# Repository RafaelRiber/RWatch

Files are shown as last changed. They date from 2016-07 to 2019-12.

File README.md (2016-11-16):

# RWatch
 
  <p align="center">
 
 <em>Early render of the watch</em>
 
## Short description
The RWatch is a modern and elegant oled "smartwatch" based around the Atmel ATSAMD21-G18A ARM Cortex M0+ Microcontroller, with a 9 DOF IMU and environmental sensing, and everything contained in a PCB the size of the screen.

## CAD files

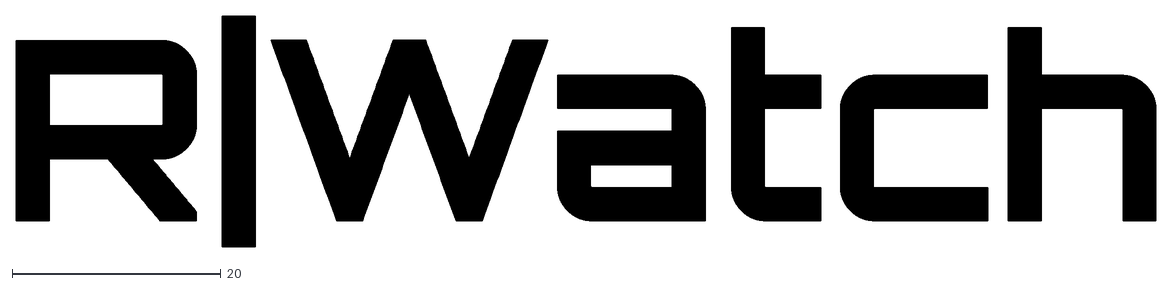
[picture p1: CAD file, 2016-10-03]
Logo/RWatch.dxf
109.3 x 22.1

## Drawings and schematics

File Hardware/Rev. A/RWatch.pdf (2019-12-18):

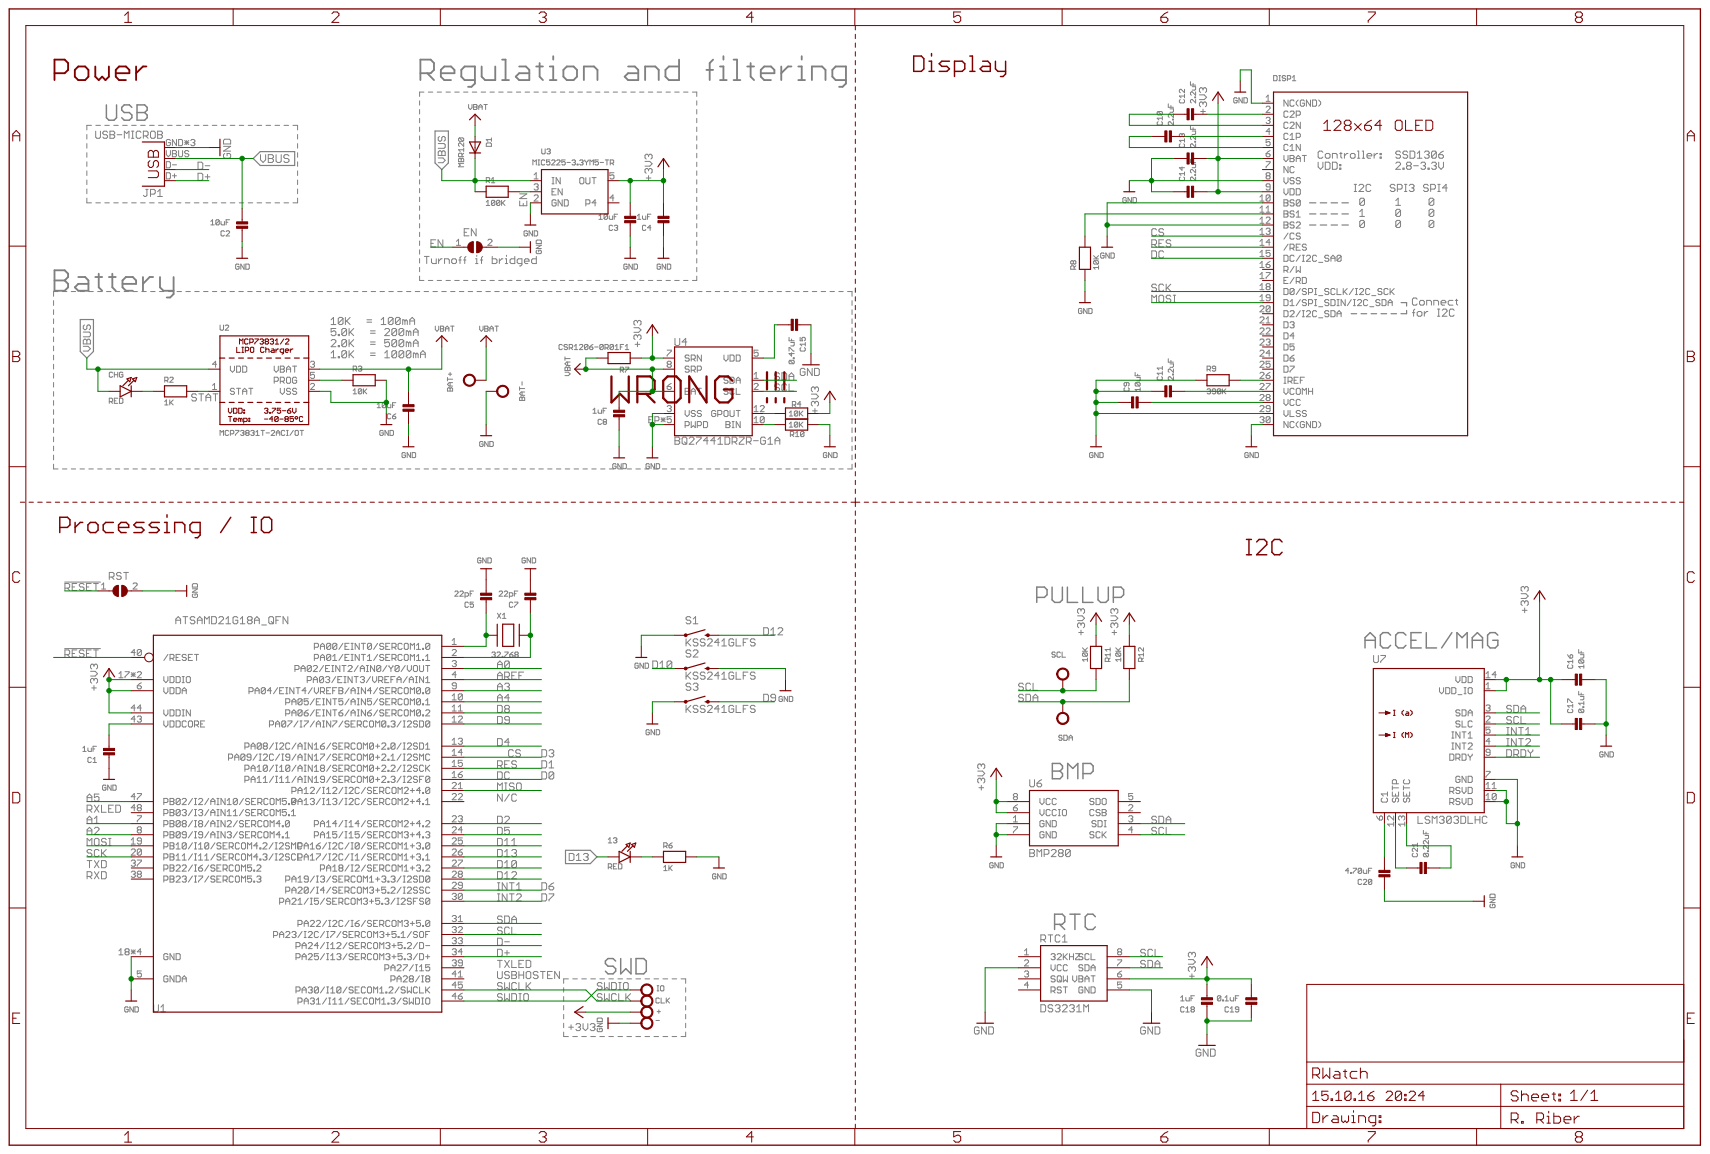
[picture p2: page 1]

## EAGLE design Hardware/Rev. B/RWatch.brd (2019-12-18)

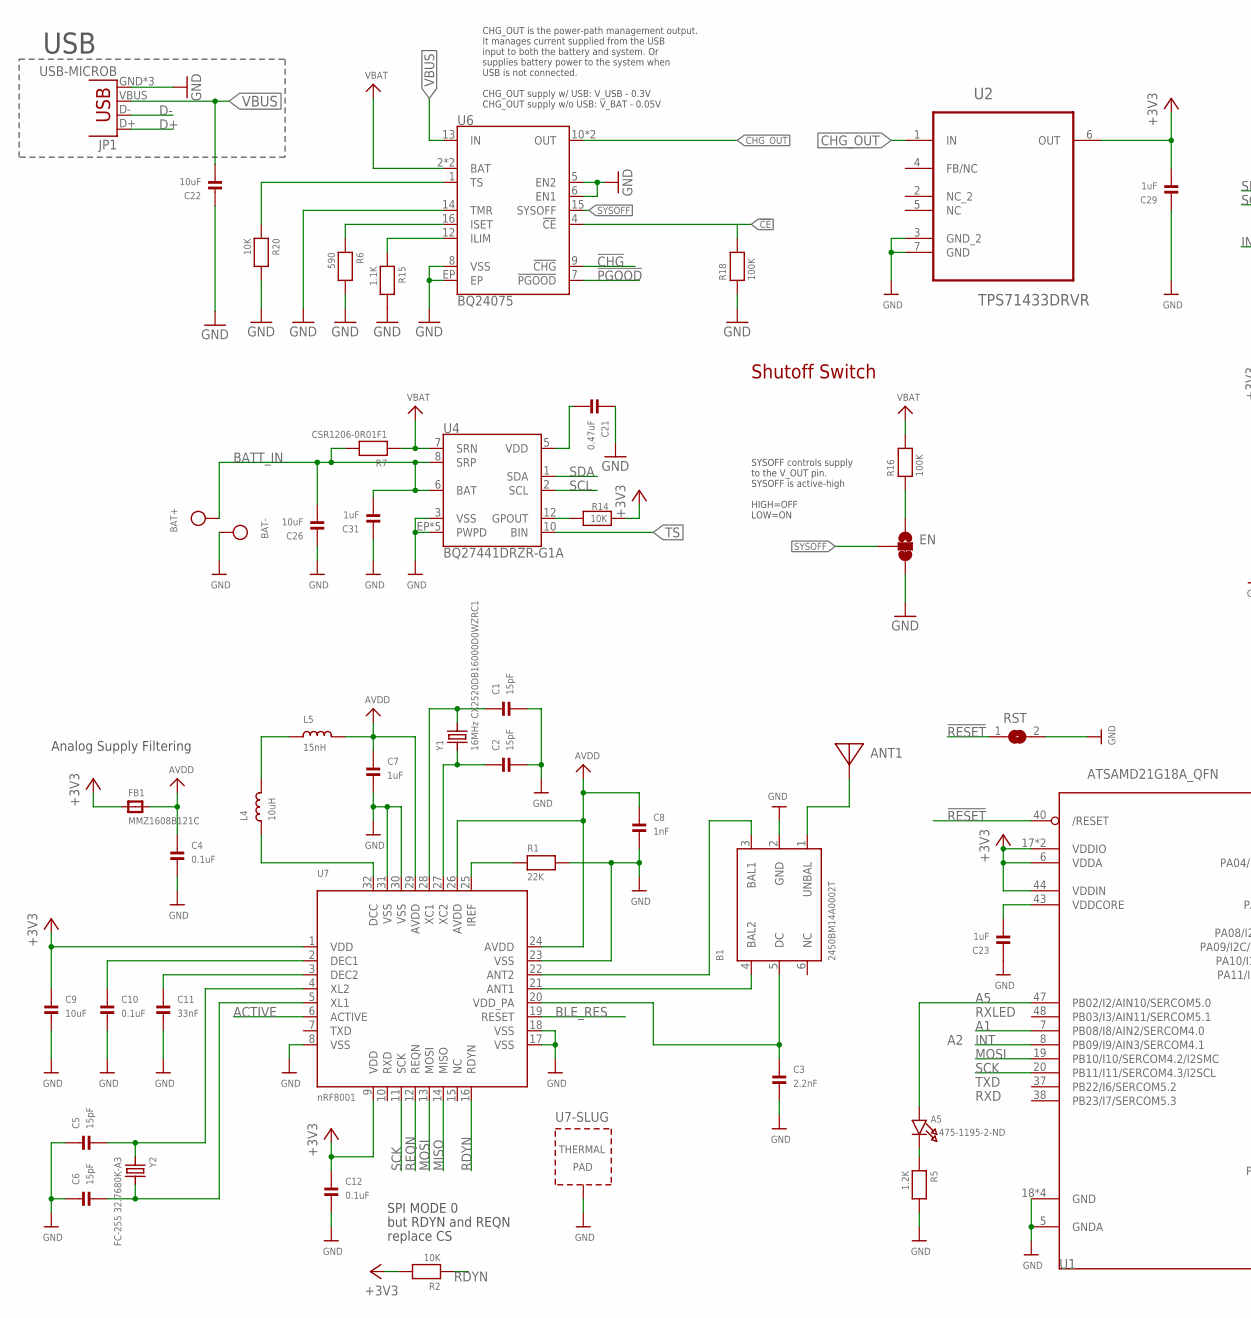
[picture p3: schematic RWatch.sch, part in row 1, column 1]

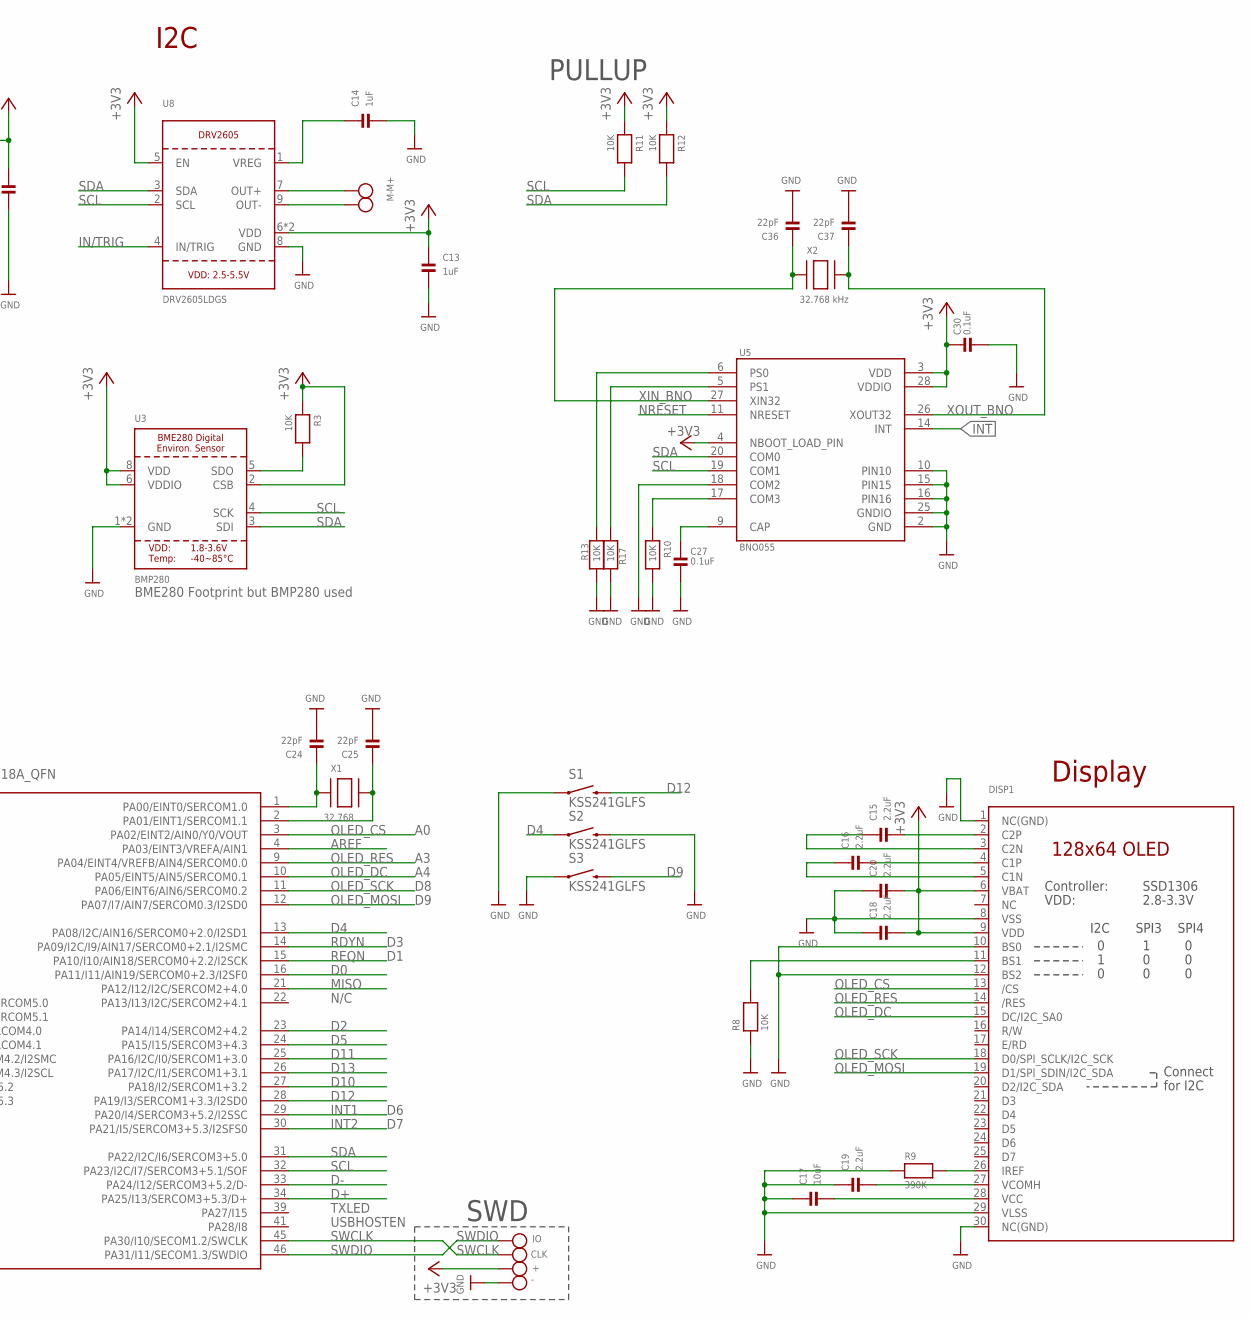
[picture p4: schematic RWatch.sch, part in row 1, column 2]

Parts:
+: TESTPOINTROUND1.5MM; TESTPOINT_ROUND_1.5MM
-: TESTPOINTROUND1.5MM; TESTPOINT_ROUND_1.5MM
A5: 475-1195-2-ND; CHIPLED_0603_NOOUTLINE
ANT1: ANTENNA_PCBNRF8001_1.6MM; ANT_PCB_2.4GHZ_NRF8001_1.6MM_1OZ
B1: 2450BM14A0002T; BALUN0603
BAT+: TESTPOINTROUND2MM; TESTPOINT_ROUND_2MM
BAT-: TESTPOINTROUND2MM; TESTPOINT_ROUND_2MM
C1, C2, C5, C6: 15pF; 0402
C3: 2.2nF; 0402
C4, C10, C12, C27, C30: 0.1uF; 0402
C7, C13, C14, C23, C29, C31: 1uF; 0402
C8: 1nF; 0402
C9: 10uF; 0402
C11: 33nF; 0402
C15, C16, C18, C19, C20: 2.2uF; 0402
C17, C22, C26: 10uF; 0603
C21: 0.47uF; 0402
C24, C25, C36, C37: 22pF; 0402
CLK: TESTPOINTROUND1.5MM; TESTPOINT_ROUND_1.5MM
DISP1: DISP_OLED_UG-2864HSWEG01; UG-2864HSWEG01_1.3_WRAPAROUND
EN: JUMPER-PAD-3-2OF3_NC_BY_TRACE_SMALL; PAD-JUMPER-3-2OF3_NC_BY_TRACE_YES_SILK_FULL_BOX
FB1: MMZ1608B121C; 0805
IO: TESTPOINTROUND1.5MM; TESTPOINT_ROUND_1.5MM
JP1: USB-MICROB; MPN 10104110-0001LF
L4: 10uH; _0603
L5: 15nH; _0603
M+: TESTPOINTROUND2MM; TESTPOINT_ROUND_2MM
M-: TESTPOINTROUND2MM; TESTPOINT_ROUND_2MM
R1: 22K; 0402
R2, R8: 10K; 0402
R3, R10, R11, R12, R13, R14, R17, R20: 10K; 0402; MPN CRCW060310K0FKEA
R5: 1.2K; 0402; MPN MC0063W06031221R
R6: 590; 0402; MPN CRCW060310K0FKEA
R7: CSR1206-0R01F1; 1206
R9: 390K; 0402
R15: 1.1K; 0402; MPN CRCW060310K0FKEA
R16, R18: 100K; 0402; MPN MC0063W06031221R
RST: SOLDERJUMPERREFLOW; SOLDERJUMPER_REFLOW
S1, S2, S3: KSS241GLFS
U1: ATSAMD21G18A_QFN; TQFN48_7MM
U2: TPS71433DRVR; SON65P200X200X80-7N
U3: BMP280; BME280
U4: BQ27441DRZR-G1A; PDSO-N12
U5: BNO055; LGA28R50P4X10_380X520X100
U6: BQ24075; PVQFN-N16
U7: nRF8001; QFN32_5MM
U8: DRV2605LDGS; PSOP10
X1: 32.768; XTAL3215
X2: 32.768 kHz; XTAL3215
Y1: 16MHz CX2520DB16000D0WZRC1; CRYSTAL_2.5X2
Y2: FC-255 32.7680K-A3; CRYSTAL_4.9X1.8

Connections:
!CE!: R18.2, U6.4 (!CE!)
!CHG!: U6.9 (!CHG!)
!PGOOD!: U6.7 (!PGOOD!)
!RESET: RST.1, U1.40 (/RESET)
+3V3: +.P$1, C9.1, C12.1, C13.1, C18.2, C20.2, C29.2, C30.2, DISP1.6 (VBAT), DISP1.9 (VDD), FB1.1, R2.2, R3.1, R11.1, R12.1, R14.1, U1.6 (VDDA), U1.17 (VDDIO), U1.36 (VDDIO), U1.44 (VDDIN), U2.6 (OUT), U3.2 (CSB), U3.6 (VDDIO), U3.8 (VDD), U5.3 (VDD), U5.4 (NBOOT_LOAD_PIN), U5.28 (VDDIO), U7.1 (VDD), U7.9 (VDD), U8.5 (EN), U8.6 (VDD), U8.10 (VDD)
A1: U1.7 (PB08/I8/AIN2/SERCOM4.0)
A5: A5.A, U1.47 (PB02/I2/AIN10/SERCOM5.0)
ACTIVE: U7.6 (ACTIVE)
AREF: U1.4 (PA03/EINT3/VREFA/AIN1)
AVDD: C4.1, C7.1, C8.1, FB1.2, L5.2, U7.24 (AVDD), U7.26 (AVDD), U7.29 (AVDD)
BATT_IN: BAT+.P$1, C26.2, C31.2, R7.2, U4.6 (BAT), U4.8 (SRP)
BLE_RES: U7.19 (RESET)
CHG_OUT: U2.1 (IN), U6.10 (OUT), U6.11 (OUT)
D0: U1.16 (PA11/I11/AIN19/SERCOM0+2.3/I2SF0)
D2: U1.23 (PA14/I14/SERCOM2+4.2)
D4: S2.1, U1.13 (PA08/I2C/AIN16/SERCOM0+2.0/I2SD1)
D5: U1.24 (PA15/I15/SERCOM3+4.3)
D9: S3.2
D10: U1.27 (PA18/I2/SERCOM1+3.2)
D11: U1.25 (PA16/I2C/I0/SERCOM1+3.0)
D12: S1.2, U1.28 (PA19/I3/SERCOM1+3.3/I2SD0)
D13: U1.26 (PA17/I2C/I1/SERCOM1+3.1)
D+: JP1.D+, U1.34 (PA25/I13/SERCOM3+5.3/D+)
D-: JP1.D-, U1.33 (PA24/I12/SERCOM3+5.2/D-)
GND: -.P$1, B1.2 (GND), BAT-.P$1, C1.2, C2.2, C3.2, C4.2, C5.1, C6.1, C7.2, C8.2, C9.2, C10.2, C11.2, C12.2, C13.2, C14.2, C17.1, C18.1, C19.1, C20.1, C21.1, C22.1, C23.1, C24.2, C25.2, C26.1, C27.1, C29.1, C30.1, C31.1, C36.2, C37.2, DISP1.1 (NC(GND)), DISP1.8 (VSS), DISP1.10 (BS0), DISP1.12 (BS2), DISP1.29 (VLSS), DISP1.30 (NC(GND)), EN.3, JP1.GND, JP1.MT1 (GND), JP1.MT2 (GND), R1.2, R5.2, R6.2, R8.1, R9.1, R10.2, R13.2, R15.2, R17.2, R18.1, R20.2, RST.2, S1.1, S2.2, S3.1, U1.5 (GNDA), U1.18 (GND), U1.35 (GND), U1.42 (GND), U1.THERMAL (GND), U2.3 (GND_2), U2.7 (GND), U3.1 (GND), U3.7 (GND), U4.3 (VSS), U4.EP (PWPD), U4.EP1 (PWPD), U4.EP2 (PWPD), U4.EP3 (PWPD), U4.EP4 (PWPD), U5.2 (GND), U5.10 (PIN10), U5.15 (PIN15), U5.16 (PIN16), U5.18 (COM2), U5.25 (GNDIO), U6.5 (EN2), U6.6 (EN1), U6.8 (VSS), U6.14 (TMR), U6.EP, U7.8 (VSS), U7.17 (VSS), U7.18 (VSS), U7.23 (VSS), U7.30 (VSS), U7.31 (VSS), U7.33 (TP), U8.8 (GND)
ILIM: R15.1, U6.12 (ILIM)
IN/TRIG: U8.4 (IN/TRIG)
INT: U1.8 (PB09/I9/AIN3/SERCOM4.1), U5.14 (INT)
INT1: U1.29 (PA20/I4/SERCOM3+5.2/I2SSC)
INT2: U1.30 (PA21/I5/SERCOM3+5.3/I2SFS0)
ISET: R6.1, U6.16 (ISET)
MISO: U1.21 (PA12/I12/I2C/SERCOM2+4.0), U7.14 (MISO)
MOSI: U1.19 (PB10/I10/SERCOM4.2/I2SMC), U7.13 (MOSI)
unnamed: ANT1.FEED, B1.1 (UNBAL)
unnamed: B1.3 (BAL1), U7.22 (ANT2)
unnamed: B1.4 (BAL2), U7.21 (ANT1)
unnamed: B1.5 (DC), C3.1, U7.20 (VDD_PA)
unnamed: L4.2, L5.1
unnamed: DISP1.11 (BS1), R8.2
unnamed: C11.1, U7.3 (DEC2)
unnamed: C10.1, U7.2 (DEC1)
unnamed: C1.1, U7.28 (XC1), Y1.3 (2)
unnamed: C2.1, U7.27 (XC2), Y1.1
unnamed: L4.1, U7.32 (DCC)
unnamed: R1.1, U7.25 (IREF)
unnamed: C21.2, U4.5 (VDD)
unnamed: C24.1, U1.1 (PA00/EINT0/SERCOM1.0), X1.P$1
unnamed: C25.1, U1.2 (PA01/EINT1/SERCOM1.1), X1.P$2
unnamed: R3.2, U3.5 (SDO)
unnamed: C14.1, U8.1 (VREG)
unnamed: R14.2, U4.12 (GPOUT)
unnamed: C5.2, U7.4 (XL2), Y2.1
unnamed: C6.2, U7.5 (XL1), Y2.2
unnamed: EN.1, R16.1
unnamed: A5.C, R5.1
unnamed: C27.2, U5.9 (CAP)
unnamed: R10.1, U5.17 (COM3)
unnamed: R17.1, U5.5 (PS1)
unnamed: R13.1, U5.6 (PS0)
unnamed: DISP1.26 (IREF), R9.2
unnamed: C15.2, DISP1.2 (C2P)
unnamed: C15.1, DISP1.3 (C2N)
unnamed: C16.2, DISP1.4 (C1P)
unnamed: C16.1, DISP1.5 (C1N)
unnamed: C17.2, DISP1.28 (VCC)
unnamed: C19.2, DISP1.27 (VCOMH)
NRESET: U5.11 (NRESET)
OLED_CS: DISP1.13 (/CS), U1.3 (PA02/EINT2/AIN0/Y0/VOUT)
OLED_DC: DISP1.15 (DC/I2C_SA0), U1.10 (PA05/EINT5/AIN5/SERCOM0.1)
OLED_MOSI: DISP1.19 (D1/SPI_SDIN/I2C_SDA), U1.12 (PA07/I7/AIN7/SERCOM0.3/I2SD0)
OLED_RES: DISP1.14 (/RES), U1.9 (PA04/EINT4/VREFB/AIN4/SERCOM0.0)
OLED_SCK: DISP1.18 (D0/SPI_SCLK/I2C_SCK), U1.11 (PA06/EINT6/AIN6/SERCOM0.2)
OUT+: M+.P$1, U8.7 (OUT+)
OUT-: M-.P$1, U8.9 (OUT-)
RDYN: R2.1, U1.14 (PA09/I2C/I9/AIN17/SERCOM0+2.1/I2SMC), U7.16 (RDYN)
REQN: U1.15 (PA10/I10/AIN18/SERCOM0+2.2/I2SCK), U7.12 (REQN)
SCK: U1.20 (PB11/I11/SERCOM4.3/I2SCL), U7.11 (SCK)
SCL: R11.2, U1.32 (PA23/I2C/I7/SERCOM3+5.1/SOF), U3.4 (SCK), U4.2 (SCL), U5.19 (COM1), U8.2 (SCL)
SDA: R12.2, U1.31 (PA22/I2C/I6/SERCOM3+5.0), U3.3 (SDI), U4.1 (SDA), U5.20 (COM0), U8.3 (SDA)
SWCLK: CLK.P$1, U1.45 (PA30/I10/SECOM1.2/SWCLK)
SWDIO: IO.P$1, U1.46 (PA31/I11/SECOM1.3/SWDIO)
SYSOFF: EN.2, U6.15 (SYSOFF)
TS: R20.1, U4.10 (BIN), U6.1 (TS)
VBAT: R7.1, R16.2, U4.7 (SRN), U6.2 (BAT), U6.3 (BAT)
VBUS: C22.2, JP1.VBUS, U6.13 (IN)
VDDCORE1: C23.2, U1.43 (VDDCORE)
XIN_BNO: C36.1, U5.27 (XIN32), X2.P$1
XOUT_BNO: C37.1, U5.26 (XOUT32), X2.P$2

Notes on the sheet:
Analog Supply Filtering
SPI MODE 0
but RDYN and REQN
replace CS
SWD
Display
PULLUP
N/C
TXLED
USBHOSTEN
RXLED
TXD
RXD
USB
I2C
CHG_OUT is the power-path management output. It manages current supplied from the USB input to both the battery and system. Or supplies battery power to the system when USB is not connected. CHG_OUT supply w/ USB: V_USB - 0.3V CHG_OUT supply w/o USB: V_BAT - 0.05V
Shutoff Switch
SYSOFF controls supply to the V_OUT pin. SYSOFF is active-high HIGH=OFF LOW=ON
BME280 Footprint but BMP280 used

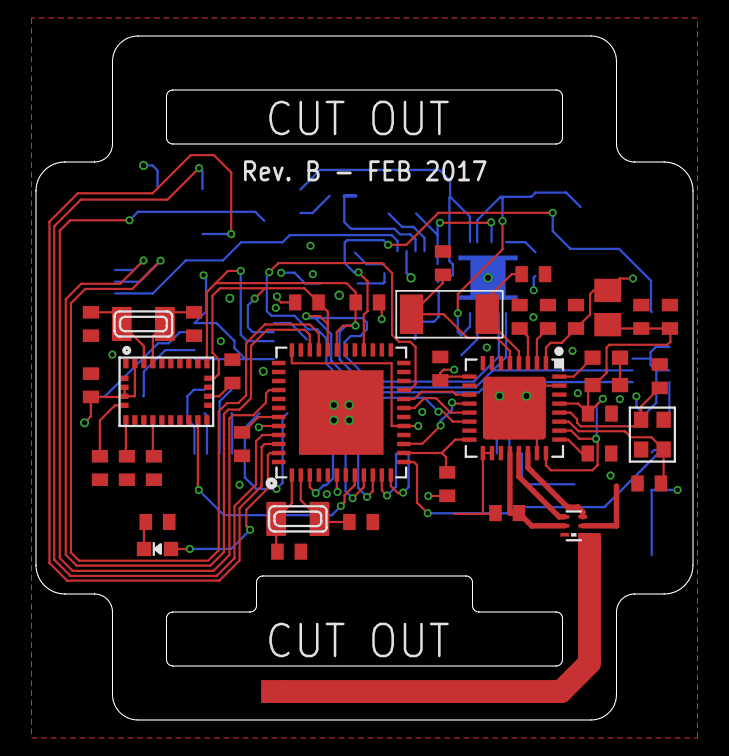
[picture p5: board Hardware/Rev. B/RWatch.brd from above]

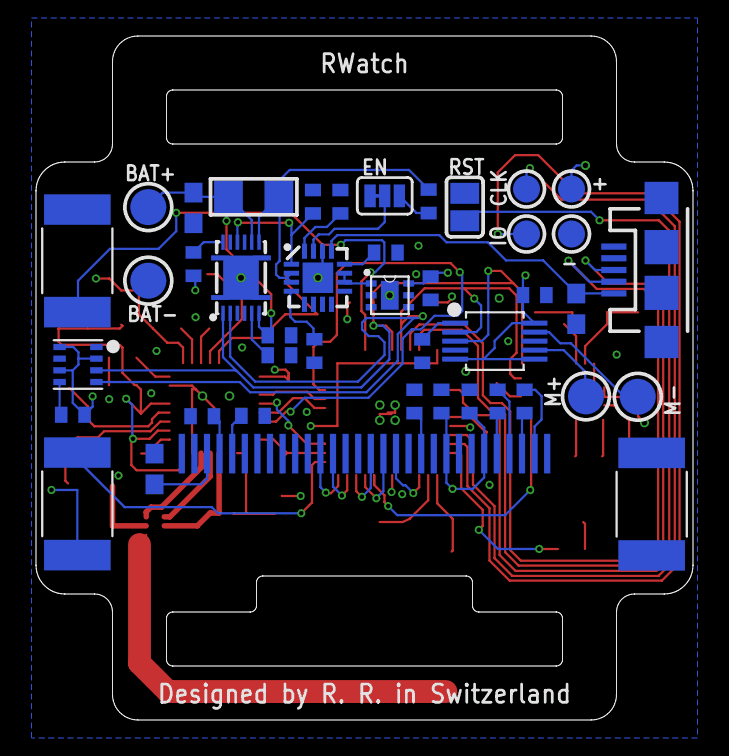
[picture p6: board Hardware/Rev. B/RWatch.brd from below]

Board: 4 copper layers, 36.5 x 38.0 mm, 83 parts (42 on the bottom side), 71 nets.

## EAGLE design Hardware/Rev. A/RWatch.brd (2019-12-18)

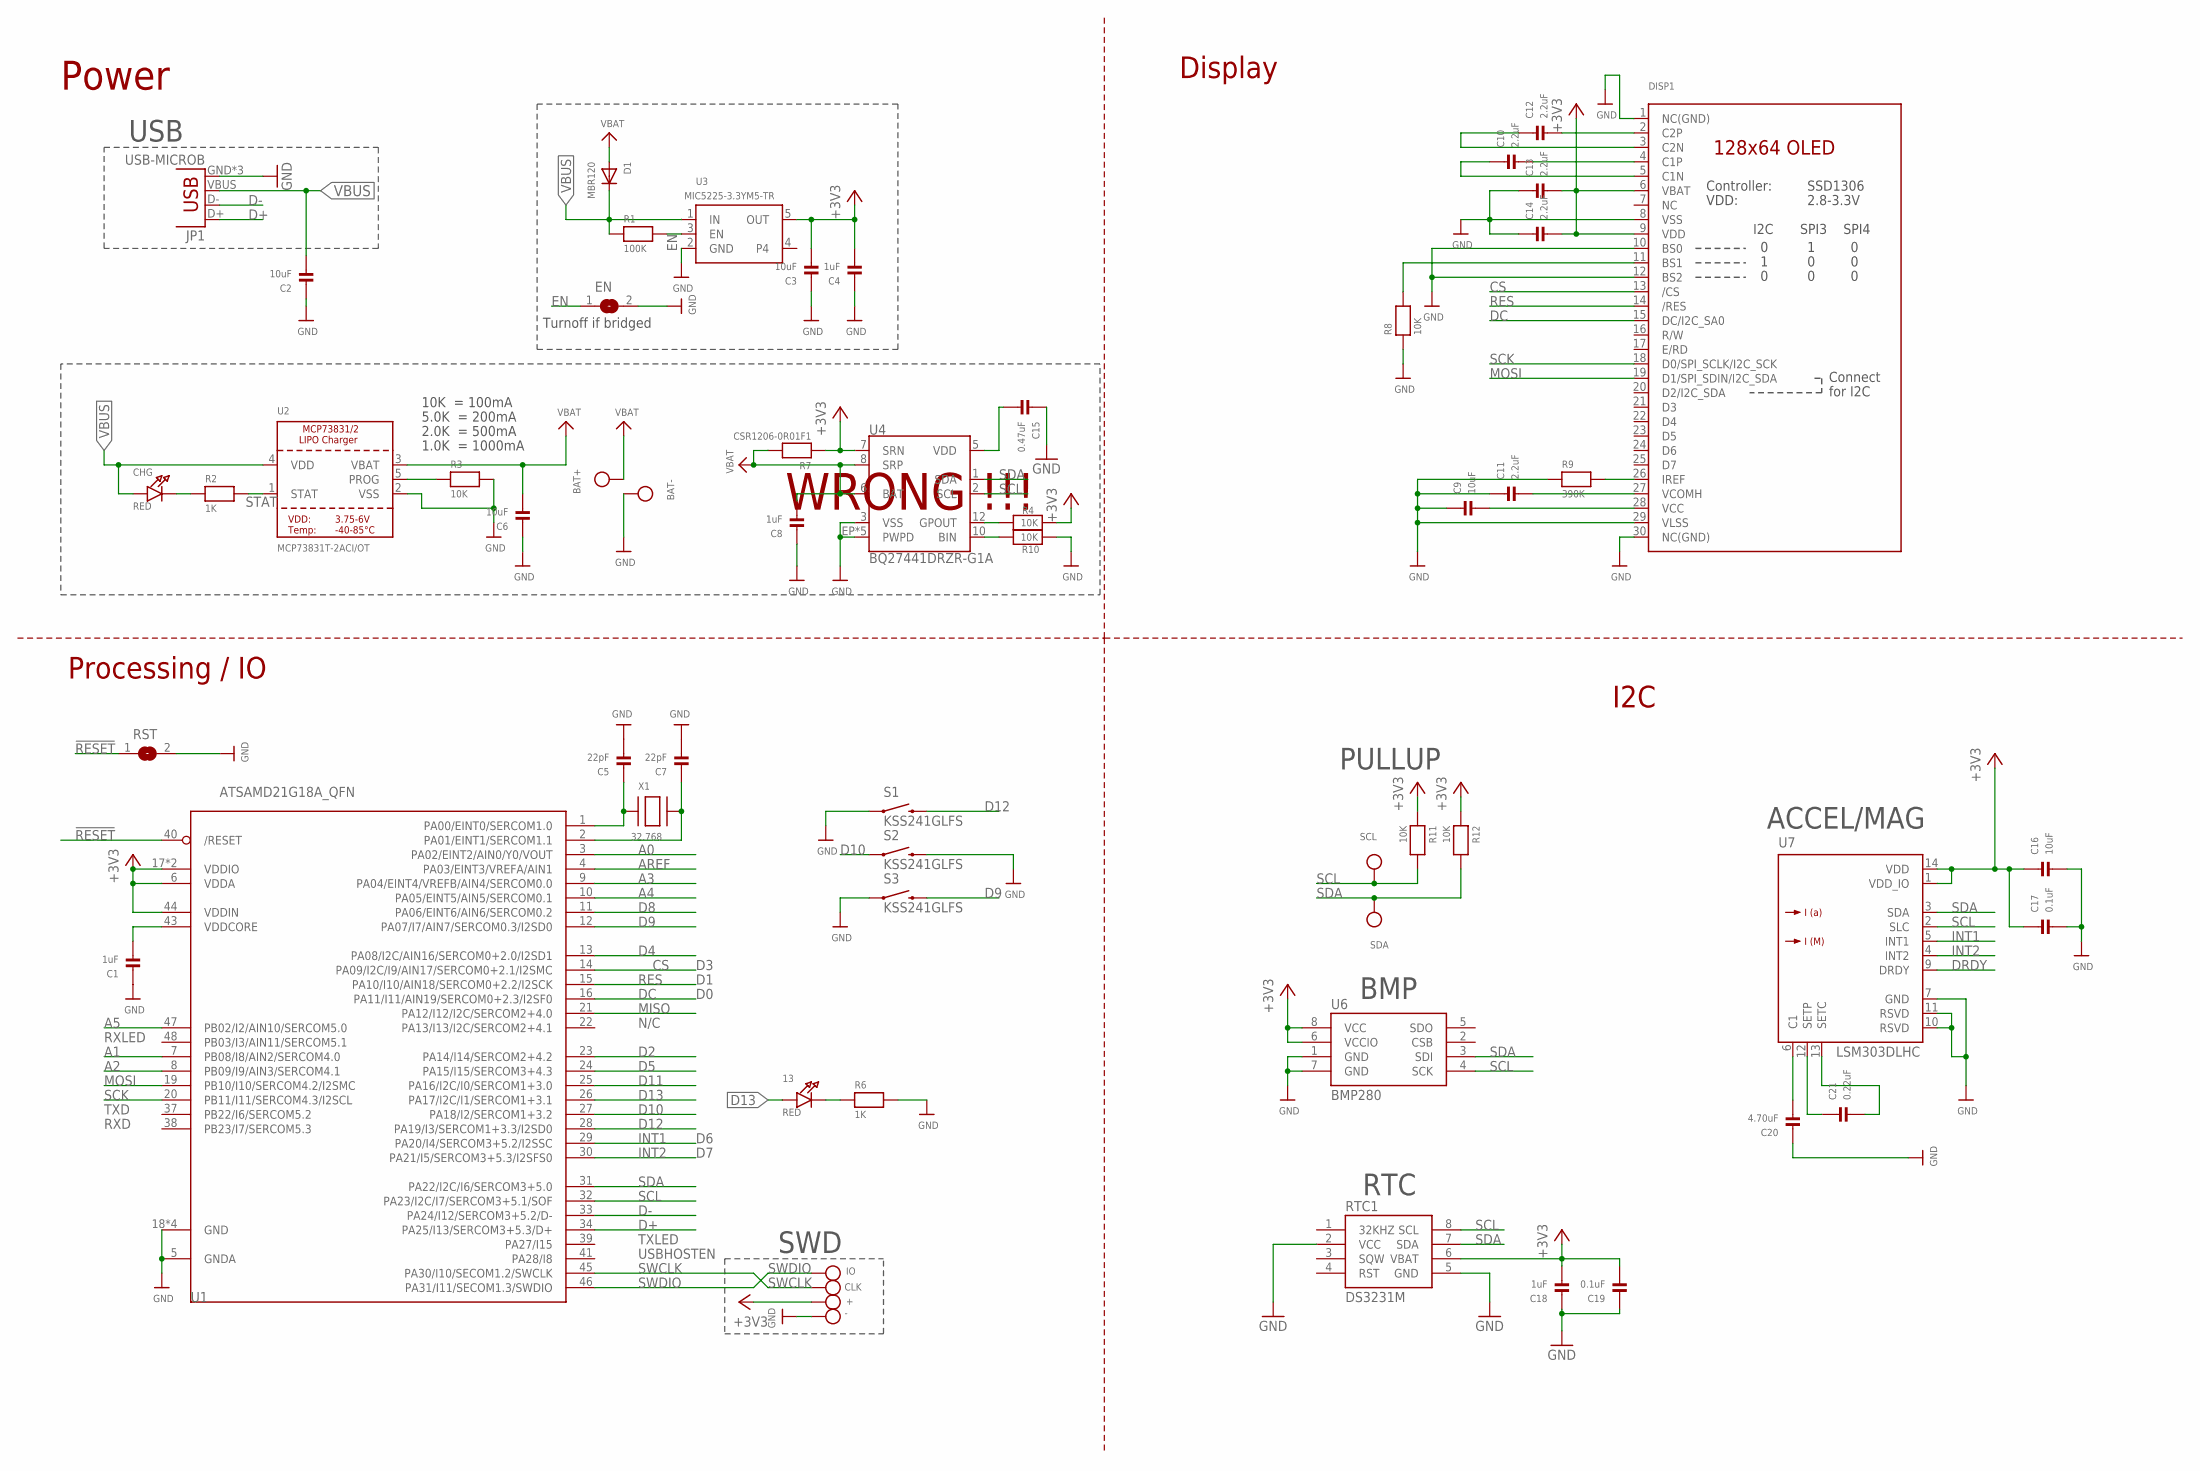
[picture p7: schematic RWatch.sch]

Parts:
13: RED; CHIPLED_0805; MPN LGQ971
+: TESTPOINTROUND1MM; TESTPOINT_ROUND_1MM
-: TESTPOINTROUND1MM; TESTPOINT_ROUND_1MM
BAT+: TESTPOINTROUND2MM; TESTPOINT_ROUND_2MM
BAT-: TESTPOINTROUND2MM; TESTPOINT_ROUND_2MM
C1, C4, C8, C18: 1uF; 0402
C2, C3, C6, C9, C16: 10uF; 0603
C5, C7: 22pF; 0402
C10, C11, C12, C13, C14: 2.2uF; 0402
C15: 0.47uF; 0402
C17, C19: 0.1uF; 0402
C20: 4.70uF; 0402
C21: 0.22uF; 0402
CHG: RED; CHIPLED_0805; MPN LGQ971
CLK: TESTPOINTROUND1MM; TESTPOINT_ROUND_1MM
D1: MBR120; SOD-123; MPN MBR120VLSFT1G
DISP1: DISP_OLED_UG-2864HSWEG01; UG-2864HSWEG01_1.3_WRAPAROUND
EN: SOLDERJUMPERREFLOW_NOPASTE; SOLDERJUMPER_REFLOW_NOPASTE
IO: TESTPOINTROUND1MM; TESTPOINT_ROUND_1MM
JP1: USB-MICROB; MPN 10104110-0001LF
R1: 100K; 0402; MPN MC0063W06031221R
R2: 1K; 0402; MPN MC0063W06031221R
R3: 10K; 0402; MPN CRCW060310K0JNEA
R4, R10, R11, R12: 10K; 0402; MPN CRCW060310K0FKEA
R6: 1K; 0402; MPN CRCW06032K20JNEA
R7: CSR1206-0R01F1; 1206
R8: 10K; 0402
R9: 390K; 0402
RST: SOLDERJUMPERREFLOW_NOPASTE; SOLDERJUMPER_REFLOW_NOPASTE
RTC1: DS3231M; SOIC8; MPN DS3231MZ+TRL
S1, S2, S3: KSS241GLFS
SCL: TESTPOINTROUND1MM; TESTPOINT_ROUND_1MM
SDA: TESTPOINTROUND1MM; TESTPOINT_ROUND_1MM
U1: ATSAMD21G18A_QFN; TQFN48_7MM
U2: MCP73831T-2ACI/OT; SOT23-5@1; MPN MCP73831T-2ACI/OT
U3: MIC5225-3.3YM5-TR; SOT23-5; MPN MIC5225-3.3YM5-TR
U4: BQ27441DRZR-G1A; PDSO-N12
U6: BMP280; LGA8
U7: LSM303DLHC; LGA-14
X1: 32.768; XTAL3215

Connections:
!RESET: RST.1, U1.40 (/RESET)
+3V3: +.P$1, C3.2, C4.2, C13.2, C14.2, C16.1, C17.1, C18.2, C19.2, DISP1.6 (VBAT), DISP1.9 (VDD), R4.1, R7.1, R11.1, R12.1, RTC1.6 (VBAT), U1.6 (VDDA), U1.17 (VDDIO), U1.36 (VDDIO), U1.44 (VDDIN), U3.5 (OUT), U4.7 (SRN), U6.6 (VCCIO), U6.8 (VCC), U7.1 (VDD_IO), U7.14 (VDD)
A0: U1.3 (PA02/EINT2/AIN0/Y0/VOUT)
A1: U1.7 (PB08/I8/AIN2/SERCOM4.0)
A2: U1.8 (PB09/I9/AIN3/SERCOM4.1)
A3: U1.9 (PA04/EINT4/VREFB/AIN4/SERCOM0.0)
A4: U1.10 (PA05/EINT5/AIN5/SERCOM0.1)
A5: U1.47 (PB02/I2/AIN10/SERCOM5.0)
AREF: U1.4 (PA03/EINT3/VREFA/AIN1)
BIN: R10.2, U4.10 (BIN)
CS: DISP1.13 (/CS), U1.14 (PA09/I2C/I9/AIN17/SERCOM0+2.1/I2SMC)
D2: U1.23 (PA14/I14/SERCOM2+4.2)
D4: U1.13 (PA08/I2C/AIN16/SERCOM0+2.0/I2SD1)
D5: U1.24 (PA15/I15/SERCOM3+4.3)
D8: U1.11 (PA06/EINT6/AIN6/SERCOM0.2)
D9: S3.2, U1.12 (PA07/I7/AIN7/SERCOM0.3/I2SD0)
D10: S2.1, U1.27 (PA18/I2/SERCOM1+3.2)
D11: U1.25 (PA16/I2C/I0/SERCOM1+3.0)
D12: S1.2, U1.28 (PA19/I3/SERCOM1+3.3/I2SD0)
D13: 13.A, U1.26 (PA17/I2C/I1/SERCOM1+3.1)
D+: JP1.D+, U1.34 (PA25/I13/SERCOM3+5.3/D+)
D-: JP1.D-, U1.33 (PA24/I12/SERCOM3+5.2/D-)
DC: DISP1.15 (DC/I2C_SA0), U1.16 (PA11/I11/AIN19/SERCOM0+2.3/I2SF0)
DRDY: U7.9 (DRDY)
EN: EN.1, R1.2, U3.3 (EN)
GND: -.P$1, BAT-.P$1, C1.1, C2.1, C3.1, C4.1, C5.2, C6.1, C7.2, C8.1, C9.1, C11.1, C13.1, C14.1, C15.1, C16.2, C17.2, C18.1, C19.1, C20.1, DISP1.1 (NC(GND)), DISP1.8 (VSS), DISP1.10 (BS0), DISP1.12 (BS2), DISP1.29 (VLSS), DISP1.30 (NC(GND)), EN.2, JP1.GND, JP1.MT1 (GND), JP1.MT2 (GND), R3.2, R6.2, R8.1, R9.1, R10.1, RST.2, RTC1.2 (VCC), RTC1.5 (GND), S1.1, S2.2, S3.1, U1.5 (GNDA), U1.18 (GND), U1.35 (GND), U1.42 (GND), U1.THERMAL (GND), U2.2 (VSS), U3.2 (GND), U4.3 (VSS), U4.EP (PWPD), U4.EP1 (PWPD), U4.EP2 (PWPD), U4.EP3 (PWPD), U4.EP4 (PWPD), U6.1 (GND), U6.7 (GND), U7.7 (GND), U7.10 (RSVD), U7.11 (RSVD)
INT1: U1.29 (PA20/I4/SERCOM3+5.2/I2SSC), U7.5 (INT1)
INT2: U1.30 (PA21/I5/SERCOM3+5.3/I2SFS0), U7.4 (INT2)
MISO: U1.21 (PA12/I12/I2C/SERCOM2+4.0)
MOSI: DISP1.19 (D1/SPI_SDIN/I2C_SDA), U1.19 (PB10/I10/SERCOM4.2/I2SMC)
unnamed: DISP1.11 (BS1), R8.2
unnamed: C15.2, U4.5 (VDD)
unnamed: C5.1, U1.1 (PA00/EINT0/SERCOM1.0), X1.P$1
unnamed: C7.1, U1.2 (PA01/EINT1/SERCOM1.1), X1.P$2
unnamed: CHG.C, R2.1
unnamed: C20.2, U7.6 (C1)
unnamed: C21.1, U7.12 (SETP)
unnamed: C21.2, U7.13 (SETC)
unnamed: R4.2, U4.12 (GPOUT)
unnamed: 13.C, R6.1
unnamed: DISP1.26 (IREF), R9.2
unnamed: C12.2, DISP1.2 (C2P)
unnamed: C12.1, DISP1.3 (C2N)
unnamed: C10.2, DISP1.4 (C1P)
unnamed: C10.1, DISP1.5 (C1N)
unnamed: C9.2, DISP1.28 (VCC)
unnamed: C11.2, DISP1.27 (VCOMH)
PROG: R3.1, U2.5 (PROG)
RES: DISP1.14 (/RES), U1.15 (PA10/I10/AIN18/SERCOM0+2.2/I2SCK)
SCK: DISP1.18 (D0/SPI_SCLK/I2C_SCK), U1.20 (PB11/I11/SERCOM4.3/I2SCL)
SCL: R11.2, RTC1.8 (SCL), SCL.P$1, U1.32 (PA23/I2C/I7/SERCOM3+5.1/SOF), U4.2 (SCL), U6.4 (SCK), U7.2 (SLC)
SDA: R12.2, RTC1.7 (SDA), SDA.P$1, U1.31 (PA22/I2C/I6/SERCOM3+5.0), U4.1 (SDA), U6.3 (SDI), U7.3 (SDA)
STAT: R2.2, U2.1 (STAT)
SWCLK: CLK.P$1, U1.45 (PA30/I10/SECOM1.2/SWCLK)
SWDIO: IO.P$1, U1.46 (PA31/I11/SECOM1.3/SWDIO)
VBAT: BAT+.P$1, C6.2, C8.2, D1.A, R7.2, U2.3 (VBAT), U4.6 (BAT), U4.8 (SRP)
VBUS: C2.2, CHG.A, D1.C, JP1.VBUS, R1.1, U2.4 (VDD), U3.1 (IN)
VDDCORE1: C1.2, U1.43 (VDDCORE)

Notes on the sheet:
SWD
Display
BMP
PULLUP
N/C
TXLED
USBHOSTEN
RXLED
TXD
RXD
10K = 100mA
5.0K = 200mA
2.0K = 500mA
1.0K = 1000mA
Power
USB
RTC
ACCEL/MAG
I2C
Processing / IO
Turnoff if bridged
WRONG !!!

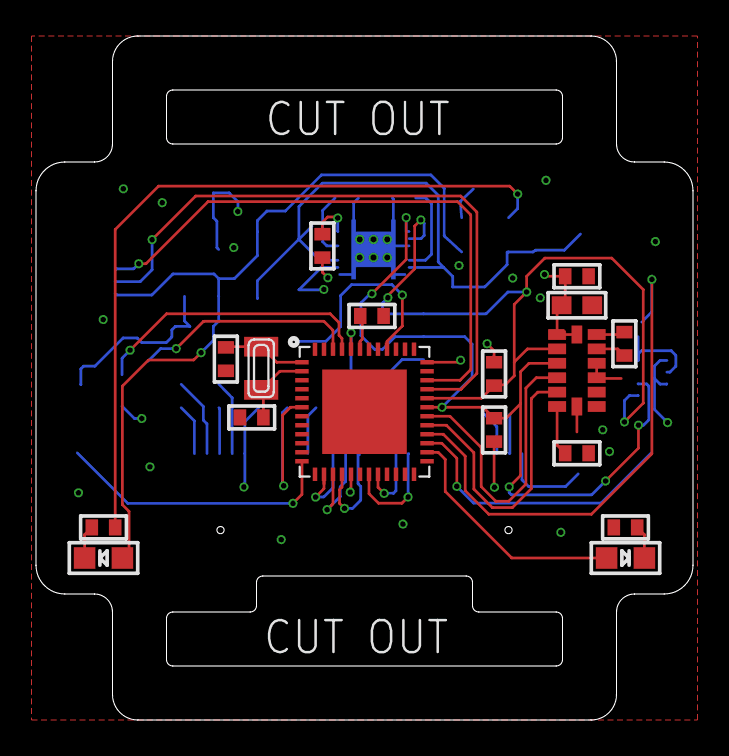
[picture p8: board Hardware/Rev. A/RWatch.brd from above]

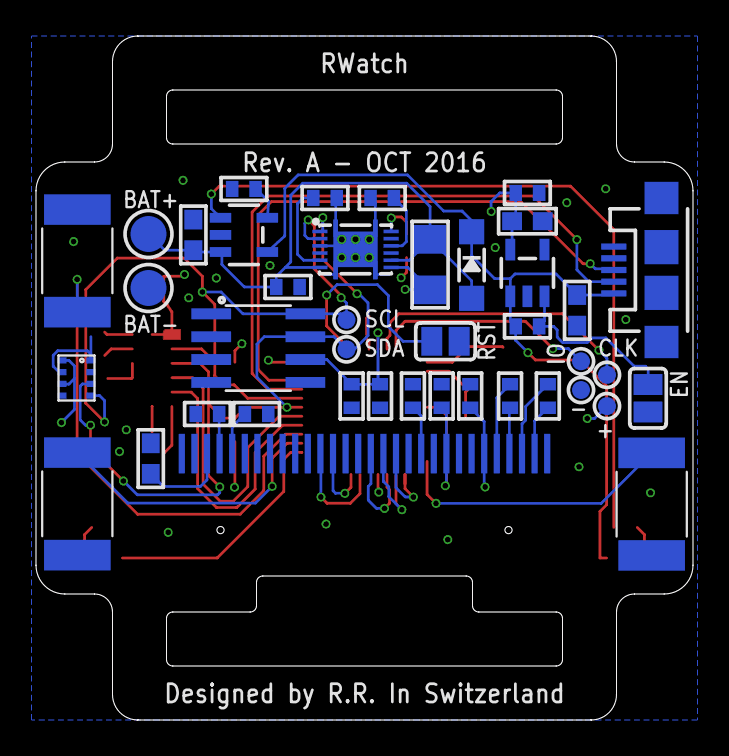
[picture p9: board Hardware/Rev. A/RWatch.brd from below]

Board: 4 copper layers, 36.5 x 38.0 mm, 58 parts (40 on the bottom side), 44 nets.

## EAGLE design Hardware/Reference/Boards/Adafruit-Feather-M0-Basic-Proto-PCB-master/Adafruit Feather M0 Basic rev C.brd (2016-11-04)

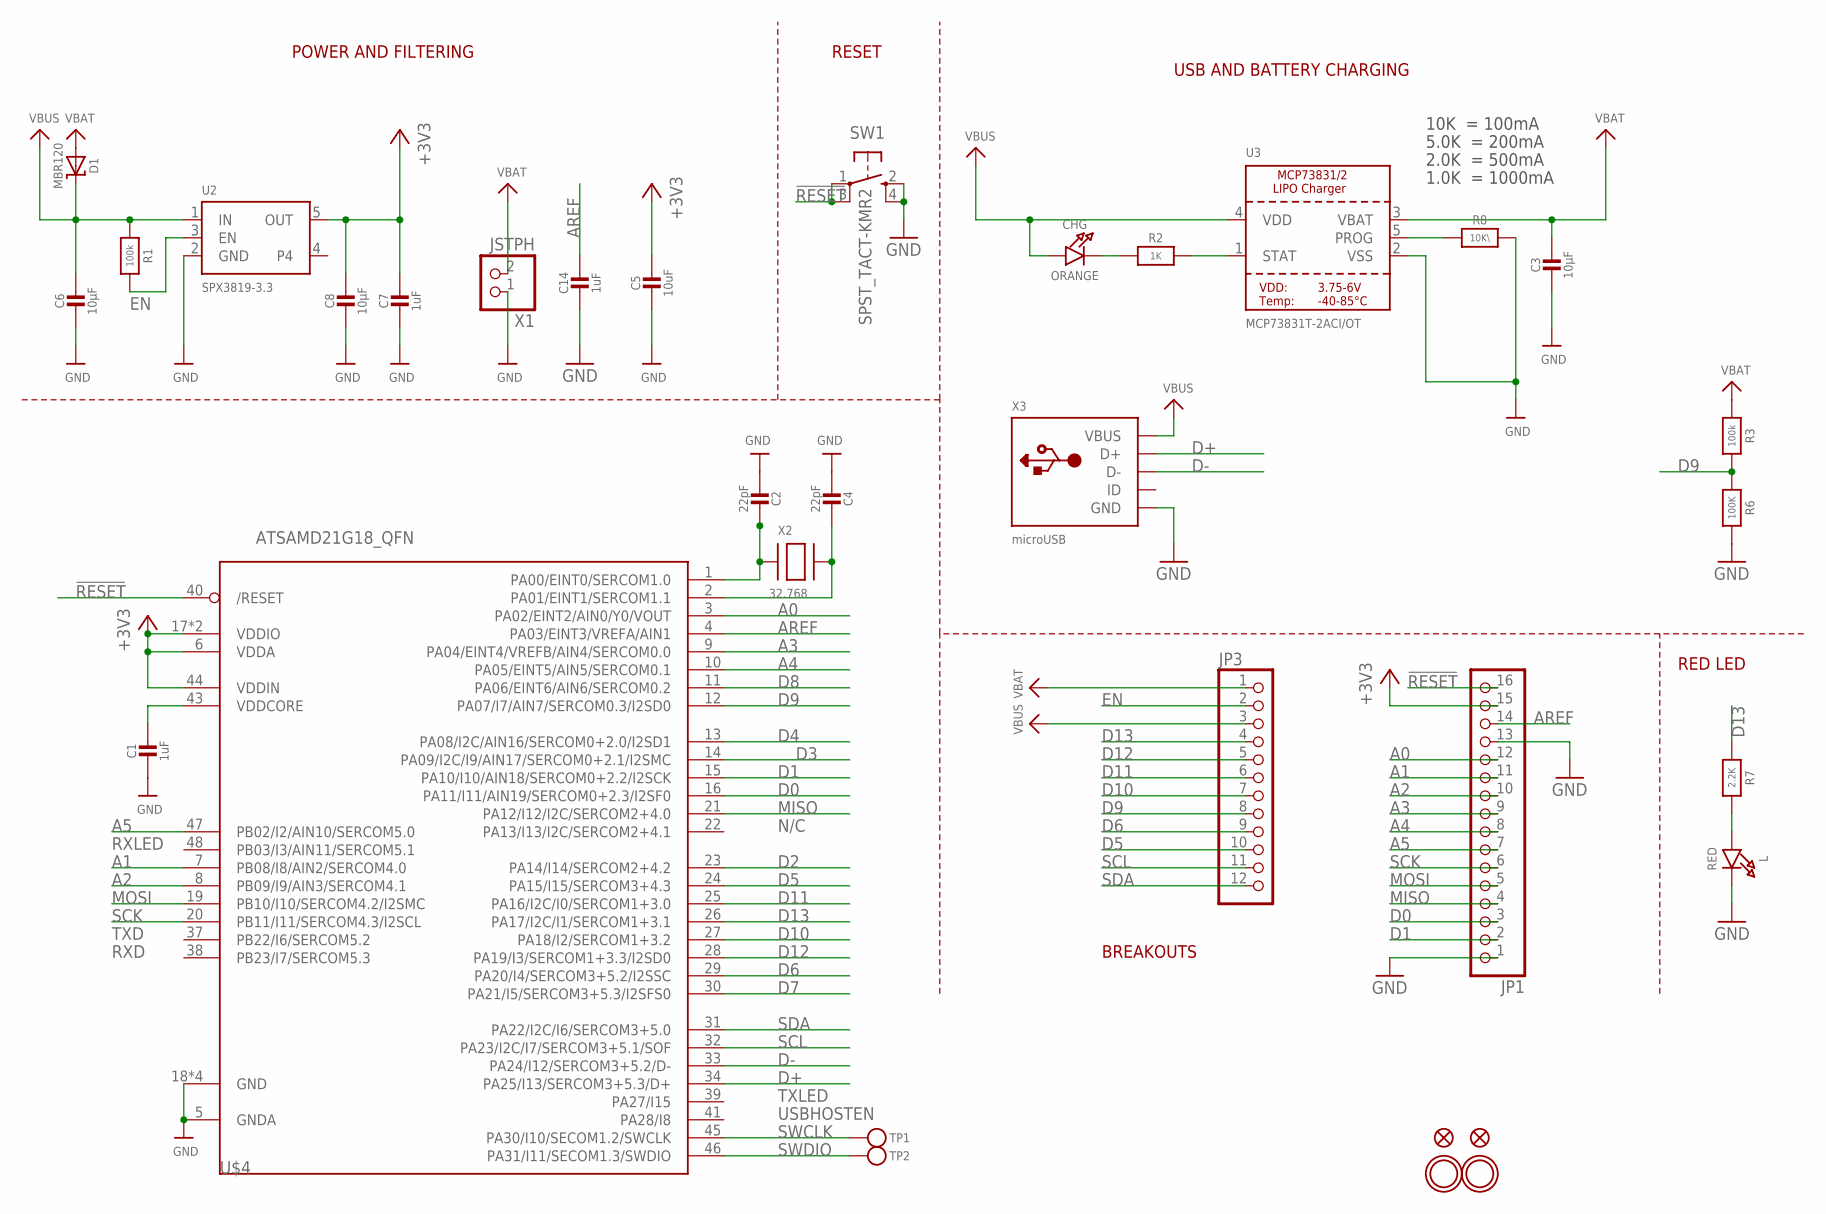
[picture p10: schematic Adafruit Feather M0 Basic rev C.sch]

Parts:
C1, C7, C14: 1uF; 0603-NO
C2, C4: 22pF; 0603-NO
C3, C6, C8: 10µF; 0805-NO
C5: 10uF; 0805-NO
CHG: ORANGE; CHIPLED_0805_NOOUTLINE
D1: MBR120; SOD-123
JP1: HEADER-1X16ROUND; 1X16_ROUND
JP3: HEADER-1X12; 1X12_ROUND
L: RED; CHIPLED_0805_NOOUTLINE
R1, R3: 100k; 0603-NO
R2: 1K; 0603-NO
R6: 100K; 0603-NO
R7: 2.2K; 0603-NO
R8: 10K\; 0603-NO
SW1: SPST_TACT-KMR2; KMR2
TP1, TP2: TESTPOINTROUND1.5MM; TESTPOINT_ROUND_1.5MM
U2: SPX3819-3.3; SOT23-5
U3: MCP73831T-2ACI/OT; SOT23-5
U$4: ATSAMD21G18_QFN; TQFN48_7MM
U$31, U$32: MOUNTINGHOLE2.5; MOUNTINGHOLE_2.5_PLATED
U$34, U$35: FIDUCIAL""; FIDUCIAL_1MM
X1: JSTPH; JSTPH2
X2: 32.768; XTAL3215
X3: microUSB; 4UCONN_20329_V2

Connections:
!RESET: JP1.16, SW1.1, SW1.3 (P1), U$4.40 (/RESET)
+3V3: C5.1, C7.1, C8.1, JP1.15, U2.5 (OUT), U$4.6 (VDDA), U$4.17 (VDDIO), U$4.36 (VDDIO), U$4.44 (VDDIN)
A0: JP1.12, U$4.3 (PA02/EINT2/AIN0/Y0/VOUT)
A1: JP1.11, U$4.7 (PB08/I8/AIN2/SERCOM4.0)
A2: JP1.10, U$4.8 (PB09/I9/AIN3/SERCOM4.1)
A3: JP1.9, U$4.9 (PA04/EINT4/VREFB/AIN4/SERCOM0.0)
A4: JP1.8, U$4.10 (PA05/EINT5/AIN5/SERCOM0.1)
A5: JP1.7, U$4.47 (PB02/I2/AIN10/SERCOM5.0)
AREF: C14.1, JP1.14, U$4.4 (PA03/EINT3/VREFA/AIN1)
D0: JP1.3, U$4.16 (PA11/I11/AIN19/SERCOM0+2.3/I2SF0)
D1: JP1.2, U$4.15 (PA10/I10/AIN18/SERCOM0+2.2/I2SCK)
D2: U$4.23 (PA14/I14/SERCOM2+4.2)
D3: U$4.14 (PA09/I2C/I9/AIN17/SERCOM0+2.1/I2SMC)
D4: U$4.13 (PA08/I2C/AIN16/SERCOM0+2.0/I2SD1)
D5: JP3.10, U$4.24 (PA15/I15/SERCOM3+4.3)
D6: JP3.9, U$4.29 (PA20/I4/SERCOM3+5.2/I2SSC)
D7: U$4.30 (PA21/I5/SERCOM3+5.3/I2SFS0)
D8: U$4.11 (PA06/EINT6/AIN6/SERCOM0.2)
D9: JP3.8, R3.2, R6.1, U$4.12 (PA07/I7/AIN7/SERCOM0.3/I2SD0)
D10: JP3.7, U$4.27 (PA18/I2/SERCOM1+3.2)
D11: JP3.6, U$4.25 (PA16/I2C/I0/SERCOM1+3.0)
D12: JP3.5, U$4.28 (PA19/I3/SERCOM1+3.3/I2SD0)
D13: JP3.4, R7.1, U$4.26 (PA17/I2C/I1/SERCOM1+3.1)
D+: U$4.34 (PA25/I13/SERCOM3+5.3/D+), X3.D+
D-: U$4.33 (PA24/I12/SERCOM3+5.2/D-), X3.D-
EN: JP3.2, R1.2, U2.3 (EN)
GND: C1.2, C2.2, C3.2, C4.2, C5.2, C6.2, C7.2, C8.2, C14.2, JP1.1, JP1.13, L.C, R6.2, R8.2, SW1.2 (S), SW1.4 (S1), U2.2 (GND), U3.2 (VSS), U$4.5 (GNDA), U$4.18 (GND), U$4.35 (GND), U$4.42 (GND), U$4.THERMAL (GND), X1.1, X3.BASE@1 (GND), X3.BASE@2 (GND), X3.GND, X3.SPRT@1 (GND), X3.SPRT@2 (GND), X3.SPRT@3 (GND), X3.SPRT@4 (GND)
MISO: JP1.4, U$4.21 (PA12/I12/I2C/SERCOM2+4.0)
MOSI: JP1.5, U$4.19 (PB10/I10/SERCOM4.2/I2SMC)
unnamed: CHG.C, R2.1
unnamed: L.A, R7.2
unnamed: R2.2, U3.1 (STAT)
unnamed: R8.1, U3.5 (PROG)
unnamed: C2.1, U$4.1 (PA00/EINT0/SERCOM1.0), X2.P$1
unnamed: C4.1, U$4.2 (PA01/EINT1/SERCOM1.1), X2.P$2
SCK: JP1.6, U$4.20 (PB11/I11/SERCOM4.3/I2SCL)
SCL: JP3.11, U$4.32 (PA23/I2C/I7/SERCOM3+5.1/SOF)
SDA: JP3.12, U$4.31 (PA22/I2C/I6/SERCOM3+5.0)
SWCLK: TP1.P$1, U$4.45 (PA30/I10/SECOM1.2/SWCLK)
SWDIO: TP2.P$1, U$4.46 (PA31/I11/SECOM1.3/SWDIO)
VBAT: C3.1, D1.A, JP3.1, R3.1, U3.3 (VBAT), X1.2
VBUS: C6.1, CHG.A, D1.C, JP3.3, R1.1, U2.1 (IN), U3.4 (VDD), X3.VBUS
VDDCORE: C1.1, U$4.43 (VDDCORE)

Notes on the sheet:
POWER AND FILTERING
RESET
10K = 100mA
5.0K = 200mA
2.0K = 500mA
1.0K = 1000mA
N/C
TXLED
USBHOSTEN
RXLED
TXD
RXD
USB AND BATTERY CHARGING
BREAKOUTS
RED LED

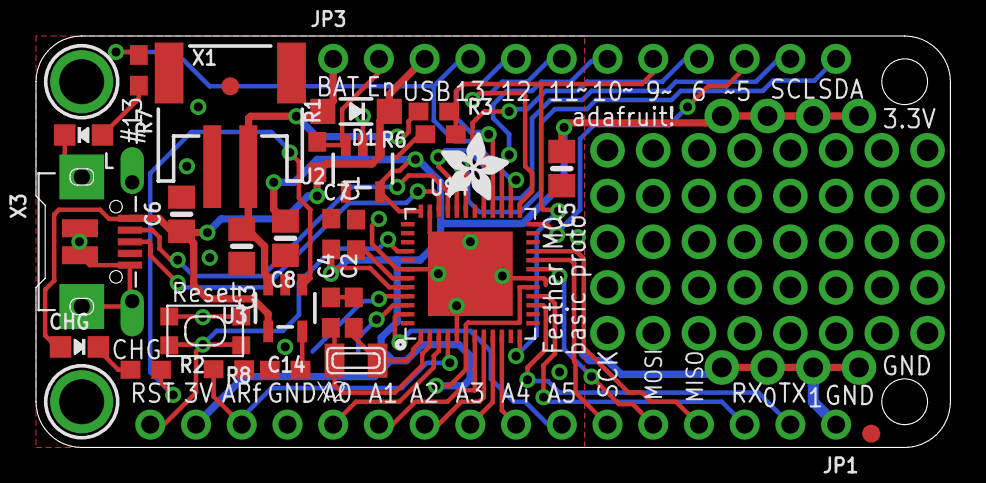
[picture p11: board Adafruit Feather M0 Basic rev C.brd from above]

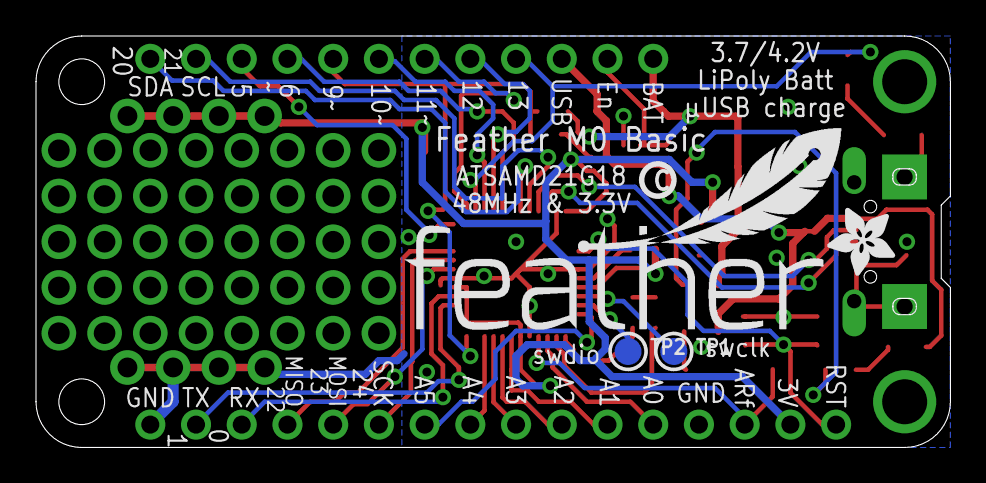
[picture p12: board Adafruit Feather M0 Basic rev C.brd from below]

Board: 2 copper layers, 50.8 x 22.9 mm, 37 parts (5 on the bottom side), 38 nets.

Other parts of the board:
U$7, U$12: ADAFRUIT_3.5MM
U$9: FEATHERLOGO
U$13: PCBFEAT-REV-040

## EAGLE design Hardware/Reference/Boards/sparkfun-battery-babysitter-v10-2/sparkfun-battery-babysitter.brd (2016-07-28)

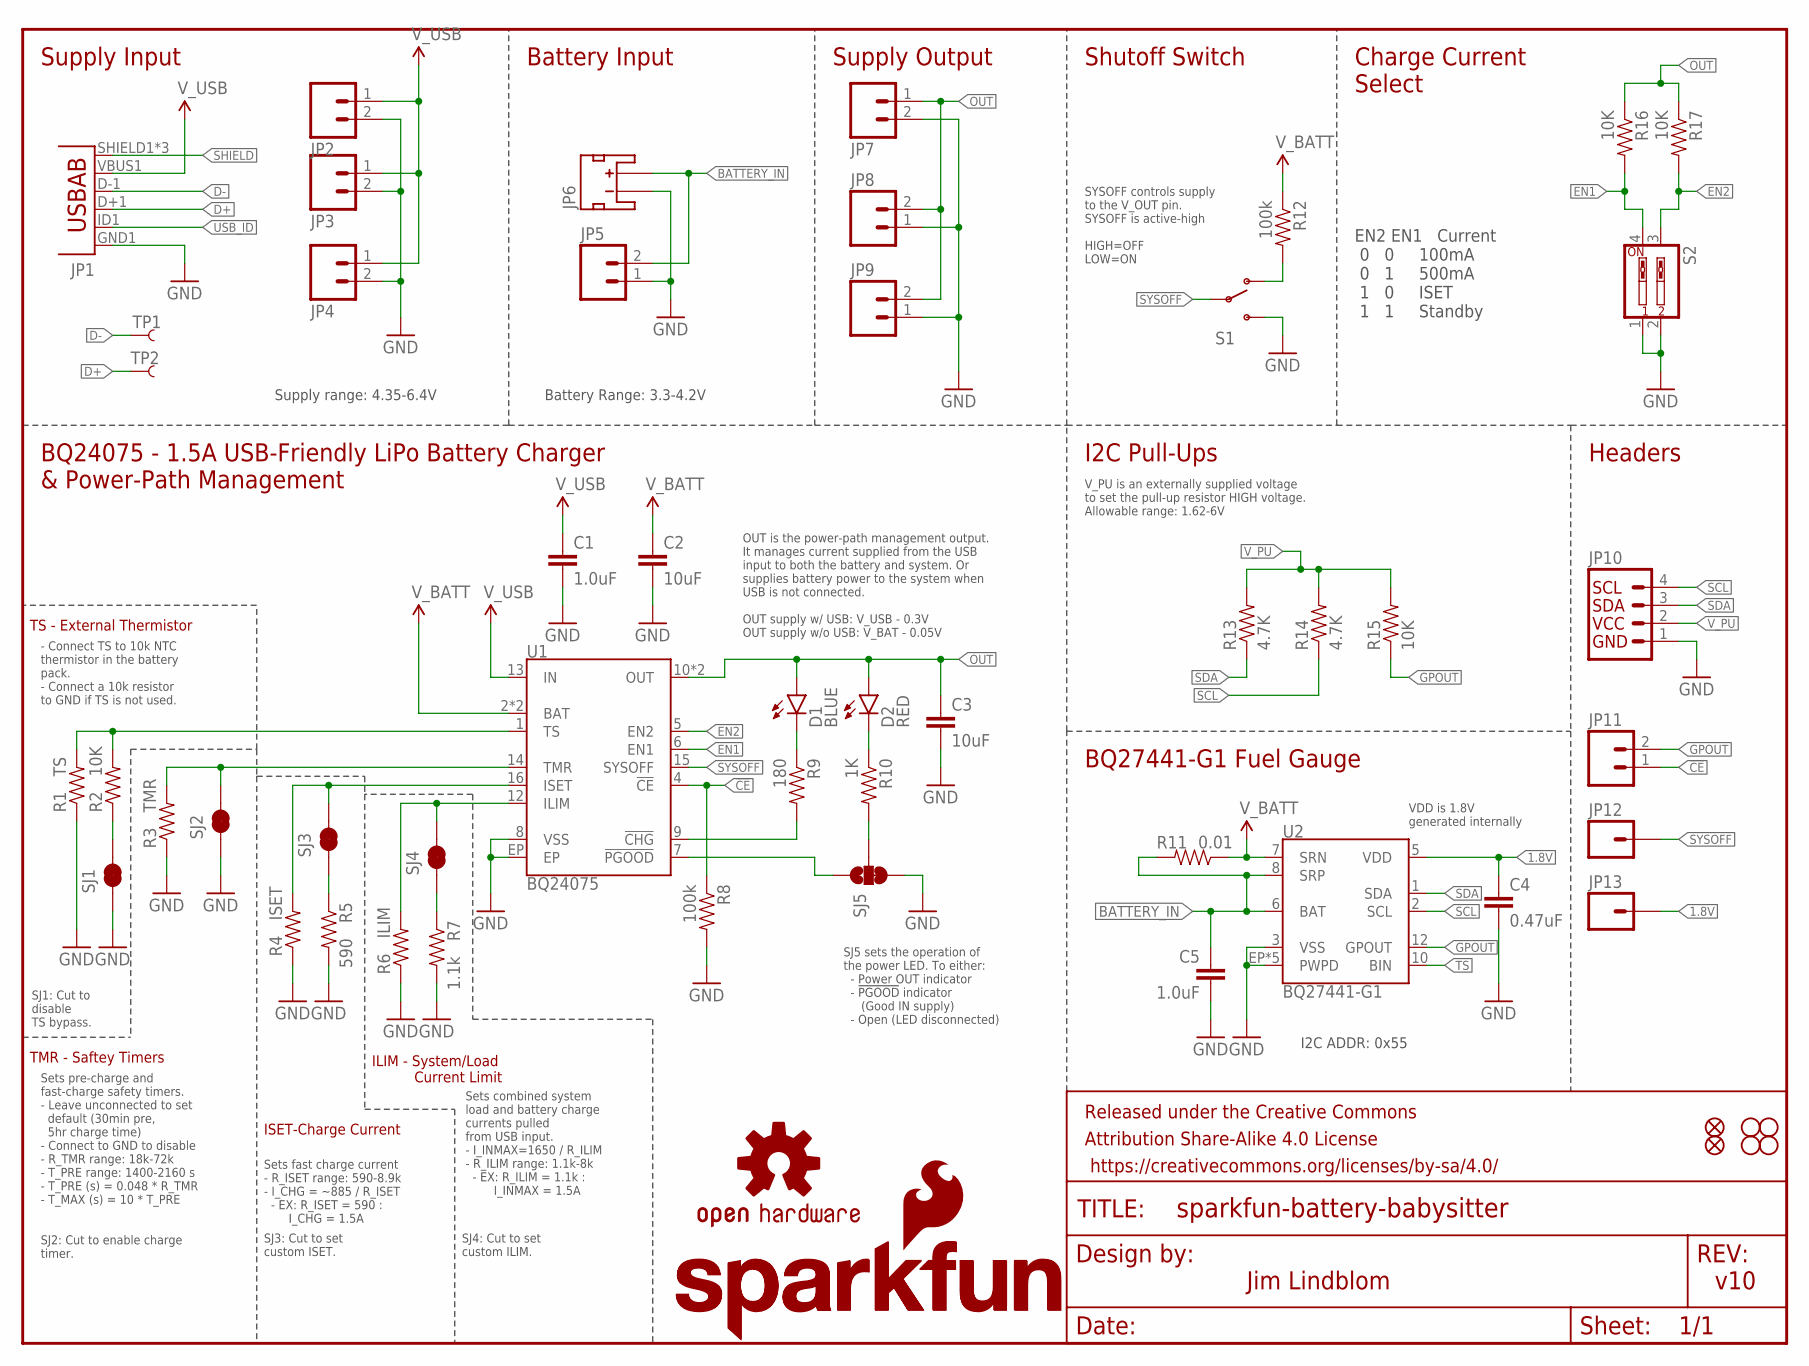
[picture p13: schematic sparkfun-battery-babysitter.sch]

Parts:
C1: 1.0uF; 1206-CAP
C2, C3: 10uF; 0805-CAP
C4: 0.47uF; 0603-CAP
C5: 1.0uF; 0603-CAP
D1: BLUE; LED-0603
D2: RED; LED-0603
FID1, FID2: FIDUCIAL1X2; FIDUCIAL-1X2
FRAME1: FRAME-LETTER; CREATIVE_COMMONS
JP1: USB-ABCONN-11794; USB-AB-MICRO-SMD_V03
JP2, JP4, JP5, JP8, JP11: M021X02_NO_SILK; 1X02_NO_SILK
JP3, JP7: M023.5MM-NO_SILK; SCREWTERMINAL-3.5MM-2-NS
JP6: JST_2MM_MALE; JST-2-SMD
JP9: M02-JST-2-PTH-NO_SILK; JST-2-PTH-NS
JP10: I2C_STANDARD_NO_SILK; 1X04_NO_SILK
JP12, JP13: M01PTH_NO_SILK_YES_STOP; 1X01_NO_SILK
LOGO1: SFE_LOGO_NAME.1_INCH; SFE_LOGO_NAME_.1
LOGO2: SFE_LOGO_NAME_FLAME.1_INCH; SFE_LOGO_NAME_FLAME_.1
LOGO3: OSHW-LOGOS; OSHW-LOGO-S
R1: TS; 1/6W-RES
R2, R15, R16, R17: 10K; 0603-RES
R3: TMR; 1/6W-RES
R4: ISET; 1/6W-RES
R5: 590; 0603-RES
R6: ILIM; 1/6W-RES
R7: 1.1k; 0603-RES
R8, R12: 100k; 0603-RES
R9: 180; 0603-RES
R10: 1K; 0603-RES
R11: 0.01; 1206
R13, R14: 4.7K; 0603-RES
S1: SWITCH-SPDT-SMD-A; SWITCH-SPST-SMD-A
S2: SW_DIP-2-SMT-HALFSIZE; DIPSWITCH-02-50MIL
SJ1, SJ2, SJ3, SJ4: JUMPER-PAD-2-NC_BY_TRACE; PAD-JUMPER-2-NC_BY_TRACE_YES_SILK
SJ5: JUMPER-PAD-3-2OF3_NC_BY_TRACE_SMALL; PAD-JUMPER-3-2OF3_NC_BY_TRACE_YES_SILK_FULL_BOX
STANDOFF1, STANDOFF2, STANDOFF3, STANDOFF4: STAND-OFF
TP1, TP2: TEST-POINT3X4; PAD.03X.04
U1: BQ24075; PVQFN-N16
U2: BQ27441-G1; PDSO-N12

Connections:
1.8V: C4.1, JP13.1, U2.5 (VDD)
!CE!: JP11.1, R8.1, U1.4 (!CE!)
!CHG!: R9.2, U1.9 (!CHG!)
!PGOOD!: SJ5.1, U1.7 (!PGOOD!)
BATTERY_IN: C5.1, JP5.2, JP6.2 (+), R11.2, U2.6 (BAT), U2.8 (SRP)
D+: JP1.D+1 (D+), TP2.P$1
D-: JP1.D-1 (D-), TP1.P$1
EN1: R16.2, S2.4, U1.6 (EN1)
EN2: R17.2, S2.3, U1.5 (EN2)
GND: C1.2, C2.2, C3.2, C4.2, C5.2, JP1.GND1 (GND), JP2.2, JP3.2, JP4.2, JP5.1, JP6.1 (-), JP7.2, JP8.1, JP9.1, JP10.1, R1.1, R3.1, R4.1, R5.2, R6.1, R7.2, R8.2, S1.3 (S), S2.1, S2.2, SJ1.1, SJ2.1, SJ5.3, U1.8 (VSS), U1.EP, U2.3 (VSS), U2.EP (PWPD), U2.EP1 (PWPD), U2.EP2 (PWPD), U2.EP3 (PWPD), U2.EP4 (PWPD)
GPOUT: JP11.2, R15.1, U2.12 (GPOUT)
ILIM: R6.2, SJ4.2, U1.12 (ILIM)
ISET: R4.2, SJ3.2, U1.16 (ISET)
unnamed: R2.1, SJ1.2
unnamed: R7.1, SJ4.1
unnamed: R5.1, SJ3.1
unnamed: R12.2, S1.1 (O)
unnamed: R10.2, SJ5.2
unnamed: D1.C, R9.1
unnamed: D2.C, R10.1
OUT: C3.1, D1.A, D2.A, JP7.1, JP8.2, JP9.2, R16.1, R17.1, U1.10 (OUT), U1.11 (OUT)
SCL: JP10.4, R14.1, U2.2 (SCL)
SDA: JP10.3, R13.1, U2.1 (SDA)
SHIELD: JP1.SHIELD1 (SHIELD), JP1.SHIELD2 (SHIELD), JP1.SHIELD3 (SHIELD)
SYSOFF: JP12.1, S1.2, U1.15 (SYSOFF)
TMR: R3.2, SJ2.2, U1.14 (TMR)
TS: R1.2, R2.2, U1.1 (TS), U2.10 (BIN)
USB_ID: JP1.ID1 (USBID)
V_BATT: C2.1, R11.1, R12.1, U1.2 (BAT), U1.3 (BAT), U2.7 (SRN)
V_PU: JP10.2, R13.2, R14.2, R15.2
V_USB: C1.1, JP1.VBUS1 (VBUS), JP2.1, JP3.1, JP4.1, U1.13 (IN)

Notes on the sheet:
EN2 EN1 Current 0 0 100mA 0 1 500mA 1 0 ISET 1 1 Standby
Sets fast charge current - R_ISET range: 590-8.9k - I_CHG = ~885 / R_ISET - EX: R_ISET = 590 : I_CHG = 1.5A
Sets combined system load and battery charge currents pulled from USB input. - I_INMAX=1650 / R_ILIM - R_ILIM range: 1.1k-8k - EX: R_ILIM = 1.1k : I_INMAX = 1.5A
Supply Input
Battery Input
Supply Output
Shutoff Switch
Charge Current Select
BQ24075 - 1.5A USB-Friendly LiPo Battery Charger & Power-Path Management
I2C Pull-Ups
BQ27441-G1 Fuel Gauge
Headers
Jim Lindblom
v10
SYSOFF controls supply to the V_OUT pin. SYSOFF is active-high HIGH=OFF LOW=ON
SJ1: Cut to disable TS bypass.
SJ3: Cut to set custom ISET.
SJ4: Cut to set custom ILIM.
ILIM - System/Load Current Limit
ISET-Charge Current
TMR - Saftey Timers
Sets pre-charge and fast-charge safety timers. - Leave unconnected to set default (30min pre, 5hr charge time) - Connect to GND to disable - R_TMR range: 18k-72k - T_PRE range: 1400-2160 s - T_PRE (s) = 0.048 * R_TMR - T_MAX (s) = 10 * T_PRE
SJ2: Cut to enable charge timer.
TS - External Thermistor
- Connect TS to 10k NTC thermistor in the battery pack. - Connect a 10k resistor to GND if TS is not used.
V_PU is an externally supplied voltage to set the pull-up resistor HIGH voltage. Allowable range: 1.62-6V
Supply range: 4.35-6.4V
VDD is 1.8V generated internally
OUT is the power-path management output. It manages current supplied from the USB input to both the battery and system. Or supplies battery power to the system when USB is not connected. OUT supply w/ USB: V_USB - 0.3V OUT supply w/o USB: V_BAT - 0.05V
I2C ADDR: 0x55
SJ5 sets the operation of the power LED. To either: - Power OUT indicator - !PGOOD! indicator (Good IN supply) - Open (LED disconnected)
Battery Range: 3.3-4.2V

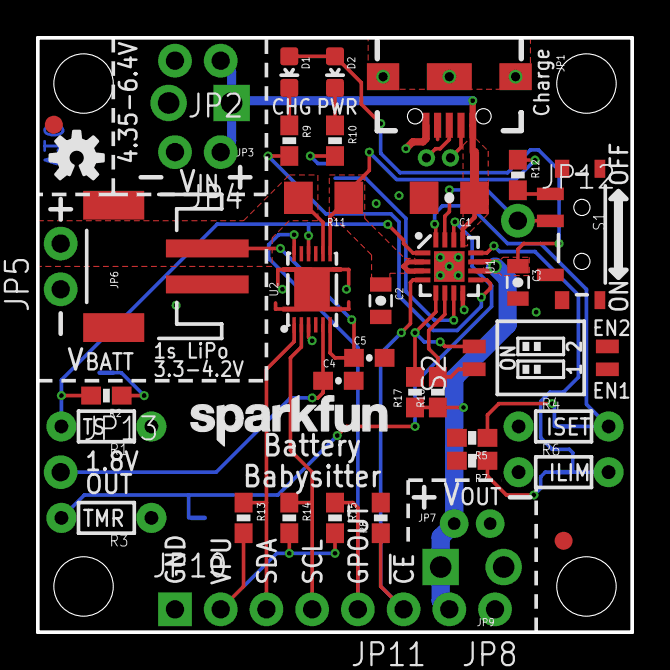
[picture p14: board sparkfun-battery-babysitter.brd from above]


Board: 2 copper layers, 33.0 x 33.0 mm, 58 parts (8 on the bottom side), 30 nets.

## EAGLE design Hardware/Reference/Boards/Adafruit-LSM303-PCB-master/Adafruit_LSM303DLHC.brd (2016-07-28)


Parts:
C1, C5: 10µF; _0805
C2: 0.1uF; _0805
C3: 4.70µF; _0805
C4: 0.22µF; _0805
FID1, FID2: FIDUCIAL""; FIDUCIAL_1MM
JP1: HEADER-1X876MIL; 1X08_ROUND_76
Q1, Q2: BSS138; SOT23-WIDE
R1, R2, R3, R4: 10K; _0805
U1: LSM303DLHC; LGA14
U2: RT9193; SOT23-5
U$3, U$4: MOUNTINGHOLE2.5; MOUNTINGHOLE_2.5_PLATED

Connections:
DRDY: JP1.5, U1.9 (DRDY)
GND: C1.2, C2.2, C3.1, C5.2, JP1.6, U1.7 (GND), U1.10 (GND), U1.11 (GND), U2.2 (GND)
INT1: JP1.4, U1.5 (INT1)
INT2: JP1.3, U1.4 (INT2)
unnamed: Q1.2 (S), R2.1, U1.3 (SDA)
unnamed: Q2.2 (S), R1.1, U1.2 (SCL)
unnamed: C3.2, U1.6 (C1)
unnamed: C4.1, U1.12 (SETP)
unnamed: C4.2, U1.13 (SETC)
SCL_5V: JP1.1, Q2.3 (D), R4.1
SDA_5V: JP1.2, Q1.3 (D), R3.1
VDD: C1.1, C2.1, JP1.8, Q1.1 (G), Q2.1 (G), R1.2, R2.2, U1.1 (VDDIO), U1.14 (VDD), U2.5 (OUT)
VIN: C5.1, JP1.7, R3.2, R4.2, U2.1 (IN), U2.3 (EN)


Board: 2 copper layers, 22.9 x 20.3 mm, 19 parts (0 on the bottom side), 13 nets.

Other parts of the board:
U$17: ADAFRUIT_3.5MM

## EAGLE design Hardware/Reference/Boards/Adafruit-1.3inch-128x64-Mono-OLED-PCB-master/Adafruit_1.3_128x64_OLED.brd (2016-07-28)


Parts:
C1, C2, C5: 10uF; 0805
C3, C4, C6, C7, C8: 2.2uF; 0805
D1, D2, D3: 1N4148; SOD-323
FID1, FID2: FIDUCIAL""; FIDUCIAL_1MM
JP1: HEADER-1X870MIL; 1X08_ROUND_70
Q1, Q2: BSS138; SOT23-WIDE
R2, R4, R5, R6, R11, R12, R13, R14: 10K; 0805
R3: 390K; 0805
SJ1, SJ2: SOLDERJUMPERREFLOW_NOPASTE; SOLDERJUMPER_REFLOW_NOPASTE
U1: UG-2864HSWEG01; UG-2864HSWEG01_1.3_WRAPAROUND
U2: VREG_SOT23-5; SOT23-5
U$23, U$24, U$25, U$26: MOUNTINGHOLE2.5; MOUNTINGHOLE_2.5_PLATED

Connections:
3.3V: C2.1, C6.2, C7.2, JP1.6, Q1.1 (G), Q2.1 (G), R4.2, R5.2, R6.2, R11.2, R12.2, SJ2.1, U1.6 (VBAT), U1.9 (VDD), U2.5 (OUT)
CS_3.3V: D1.A, R4.1, U1.13 (/CS)
CS_5.0V: D1.C, JP1.5
D0/SCLK/SCK_3.3V: Q2.2 (S), R12.1, U1.18 (D0/SPI_SCLK/I2C_SCK)
D0/SCLK/SCK_5.0V: JP1.2, Q2.3 (D), R14.1
D1/MOSI/SDA1_3.3V: Q1.2 (S), R11.1, SJ1.1, U1.19 (D1/SPI_SDIN/I2C_SDA)
D1/MOSI/SDA_5.0V: JP1.1, Q1.3 (D), R13.1
DC/SA0_3.3V: D3.A, R6.1, U1.15 (DC/I2C_SA0)
DC/SA0_5.0V: D3.C, JP1.3
GND: C1.2, C2.2, C5.1, C6.1, C7.1, C8.1, JP1.8, R2.1, R3.1, U1.1 (NC(GND)), U1.8 (VSS), U1.10 (BS0), U1.12 (BS2), U1.29 (VLSS), U1.30 (NC(GND)), U2.2 (GND)
unnamed: R2.2, SJ2.2, U1.11 (BS1)
unnamed: SJ1.2, U1.20 (D2/I2C_SDA)
unnamed: R3.2, U1.26 (IREF)
unnamed: C3.2, U1.2 (C2P)
unnamed: C3.1, U1.3 (C2N)
unnamed: C4.2, U1.4 (C1P)
unnamed: C4.1, U1.5 (C1N)
unnamed: C5.2, U1.28 (VCC)
unnamed: C8.2, U1.27 (VCOMH)
RST_3.3V: D2.A, R5.1, U1.14 (/RES)
RST_5.0V: D2.C, JP1.4
VIN: C1.1, JP1.7, R13.2, R14.2, U2.1 (IN), U2.3 (EN)

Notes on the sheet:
Bus default = SPI4
Close SJ2 for I2C
= 011110+SA0+RW
= 0x7A with DC/SA0_5.0V floating/high
= 0x78 with DC/SA0_5.0V at GND
I2C Address
ToDo: Change address to default low
Close for
I2C



Board: 2 copper layers, 35.0 x 35.5 mm, 35 parts (28 on the bottom side), 22 nets.

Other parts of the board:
U$27: ADAFRUIT_2.5MM
U$28: LOGIC_5VREADY_5MM

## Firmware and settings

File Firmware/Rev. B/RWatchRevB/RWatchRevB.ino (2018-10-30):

/**
  The MIT License (MIT)
  Copyright (c) 2016 Rafael Riber
  Permission is hereby granted, free of charge, to any person obtaining a copy
  of this software and associated documentation files (the "Software"), to deal
  in the Software without restriction, including without limitation the rights
  to use, copy, modify, merge, publish, distribute, sublicense, and/or sell
  copies of the Software, and to permit persons to whom the Software is
  furnished to do so, subject to the following conditions:
  The above copyright notice and this permission notice shall be included in all
  copies or substantial portions of the Software.
  THE SOFTWARE IS PROVIDED "AS IS", WITHOUT WARRANTY OF ANY KIND, EXPRESS OR
  IMPLIED, INCLUDING BUT NOT LIMITED TO THE WARRANTIES OF MERCHANTABILITY,
  FITNESS FOR A PARTICULAR PURPOSE AND NONINFRINGEMENT. IN NO EVENT SHALL THE
  AUTHORS OR COPYRIGHT HOLDERS BE LIABLE FOR ANY CLAIM, DAMAGES OR OTHER
  LIABILITY, WHETHER IN AN ACTION OF CONTRACT, TORT OR OTHERWISE, ARISING FROM,
  OUT OF OR IN CONNECTION WITH THE SOFTWARE OR THE USE OR OTHER DEALINGS IN THE
  SOFTWARE.
**/

/*
Free sercom
Pin  Arduino 'Pin' SERCOM    SERCOM alt
-----------------------------------------
PA18  D10          SERCOM1.2 SERCOM3.2
PA16  D11          SERCOM1.0 SERCOM3.0
PA19  D12          SERCOM1.3 SERCOM3.3
PA17  D13          SERCOM1.1 SERCOM3.1
 */

#include <SPI.h>
#include <Wire.h>
#include <Adafruit_Sensor.h>
#include "NAxisMotion.h"
#include <Adafruit_GFX.h>
#include <Adafruit_SSD1306.h>
#include <Adafruit_BMP280.h>
#include <RTCZero.h>
#include <Chrono.h>
#include <LowPower.h>
#include <Button.h>
//#include <SparkFunBQ27441.h>
#include <StopWatch.h>
#include <Adafruit_DRV2605.h>
#include <BLEPeripheral.h>
#include <BLEUtil.h>

#define OLED_MOSI   10 //FINAL: ??, PROTO: 10
#define OLED_CLK   11  //FINAL: ??, PROTO: 11
#define OLED_DC    12  //FINAL: ??, PROTO: 12
#define OLED_CS    A0  //FINAL: ??, PROTO: A0
#define OLED_RESET A1  //FINAL: ??, PROTO: A1
#define B1Pin       5  //FINAL: ??, PROTO: 5
#define B2Pin       6  //FINAL: ??, PROTO: 6
#define B3Pin       9  //FINAL: ??, PROTO: 9
#define BLE_REQ   A3   //FINAL: ??, PROTO: A3
#define BLE_RDY   A4   //FINAL: ??, PROTO: A4
#define BLE_RST   A5   //FINAL: ??, PROTO: A5
#define BNO_INT_PIN A2 //FINAL: ??, PROTO: A2

//flappy
#define ANIM_FRAME 50
#define DELAY_FRAME 1

Adafruit_SSD1306 display(OLED_MOSI, OLED_CLK, OLED_DC, OLED_RESET, OLED_CS);

Adafruit_DRV2605 drv;
NAxisMotion bno;
Adafruit_BMP280 bmp;
StopWatch stopwatch;
Chrono myChrono(Chrono::SECONDS);
Button Button1(B1Pin, false, true, 20);  //Select
Button Button2(B2Pin, false, true, 20); //Right
Button Button3(B3Pin, false, true, 20); //Left
BLEPeripheral blePeripheral = BLEPeripheral(BLE_REQ, BLE_RDY, BLE_RST);
BLEBondStore bleBondStore;
// remote services
BLERemoteService ancsService = BLERemoteService("7905f431b5ce4e99a40f4b1e122d00d0");
// remote characteristics
BLERemoteCharacteristic ancsNotificationSourceCharacteristic = BLERemoteCharacteristic("9fbf120d630142d98c5825e699a21dbd", BLENotify);
RTCZero rtc;

const unsigned int BATTERY_CAPACITY = 500;
int timer;
float QFF = 1020.00;
int chronoDeci;
int chronoHour;
int chronoSeconds;
int chronoMinutes;
int chronoCounting = 0;
bool shouldBeSleeping = false;
int inMenu = 0;
int modeInMenu;
int mode;
//int timeout = 10000;
int timeout = 10000000000;
int first_millis;
bool bleConnected = false;

char* daysOfTheWeek[] = {"SUN", "MON", "TUE", "WED", "THU", "FRI", "SAT"};

const unsigned char RWatch_logo[] PROGMEM = {
  0x00, 0x00, 0x00, 0x00, 0x00, 0x00, 0x00, 0x00, 0x00, 0x00, 0x00, 0x00, 0x00, 0x00, 0x00, 0x00,
  0x00, 0x00, 0x00, 0x00, 0x00, 0x00, 0x00, 0x00, 0x00, 0x00, 0x00, 0x00, 0x00, 0x00, 0x00, 0x00,
  0x00, 0x00, 0x00, 0x00, 0x00, 0x00, 0x00, 0x00, 0x00, 0x00, 0x00, 0x00, 0x00, 0x00, 0x00, 0x00,
  0x00, 0x00, 0x00, 0x00, 0x00, 0x00, 0x00, 0x00, 0x00, 0x00, 0x00, 0x00, 0x00, 0x00, 0x00, 0x00,
  0x00, 0x00, 0x00, 0x00, 0x00, 0x00, 0x00, 0x00, 0x00, 0x00, 0x00, 0x00, 0x00, 0x00, 0x00, 0x00,
  0x00, 0x00, 0x00, 0x00, 0x00, 0x00, 0x00, 0x00, 0x00, 0x00, 0x00, 0x00, 0x00, 0x00, 0x00, 0x00,
  0x00, 0x00, 0x00, 0x00, 0x00, 0x00, 0x00, 0x00, 0x00, 0x00, 0x00, 0x00, 0x00, 0x00, 0x00, 0x00,
  0x00, 0x00, 0x00, 0x00, 0x00, 0x00, 0x00, 0x00, 0x00, 0x00, 0x00, 0x00, 0x00, 0x00, 0x00, 0x00,
  0x00, 0x00, 0x00, 0x00, 0x00, 0x00, 0x00, 0x00, 0x00, 0x00, 0x00, 0x00, 0x00, 0x00, 0x00, 0x00,
  0x00, 0x00, 0x00, 0x00, 0x00, 0x00, 0x00, 0x00, 0x00, 0x00, 0x00, 0x00, 0x00, 0x00, 0x00, 0x00,
  0x00, 0x00, 0x00, 0x00, 0x00, 0x00, 0x00, 0x00, 0x00, 0x00, 0x00, 0x00, 0x00, 0x00, 0x00, 0x00,
  0x00, 0x00, 0x00, 0x00, 0x00, 0x00, 0x00, 0x00, 0x00, 0x00, 0x00, 0x00, 0x00, 0x00, 0x00, 0x00,
  0x00, 0x00, 0x00, 0x00, 0x00, 0x00, 0x00, 0x00, 0x00, 0x00, 0x00, 0x00, 0x00, 0x00, 0x00, 0x00,
  0x00, 0x00, 0x00, 0x00, 0x00, 0x00, 0x00, 0x00, 0x00, 0x00, 0x00, 0x00, 0x00, 0x00, 0x00, 0x00,
  0x00, 0x00, 0x00, 0x00, 0x00, 0x00, 0x00, 0x00, 0x00, 0x00, 0x00, 0x00, 0x00, 0x00, 0x00, 0x00,
  0x00, 0x00, 0x00, 0x00, 0x00, 0x00, 0x00, 0x00, 0x00, 0x00, 0x00, 0x00, 0x00, 0x00, 0x00, 0x00,
  0x00, 0x00, 0x00, 0x00, 0x00, 0x00, 0x00, 0x00, 0x00, 0x00, 0x00, 0x00, 0x00, 0x00, 0x00, 0x00,
  0x00, 0x00, 0x00, 0x00, 0x00, 0x00, 0x00, 0x00, 0x00, 0x00, 0x00, 0x00, 0x00, 0x00, 0x00, 0x00,
  0x00, 0x00, 0x00, 0xf0, 0x00, 0x00, 0x00, 0x00, 0x00, 0x00, 0x00, 0x00, 0x00, 0x00, 0x00, 0x00,
  0x00, 0x00, 0x00, 0xf0, 0x00, 0x00, 0x00, 0x00, 0x00, 0x00, 0x70, 0x00, 0x00, 0x01, 0xe0, 0x00,
  0x00, 0x00, 0x00, 0xf0, 0x00, 0x00, 0x00, 0x00, 0x00, 0x00, 0xf0, 0x00, 0x00, 0x01, 0xe0, 0x00,
  0x3f, 0xff, 0xf0, 0xf3, 0xc0, 0x1e, 0x00, 0xf0, 0x00, 0x00, 0xf0, 0x00, 0x00, 0x01, 0xe0, 0x00,
  0x3f, 0xff, 0xf8, 0xf3, 0xc0, 0x1e, 0x00, 0xf0, 0x00, 0x00, 0xf0, 0x00, 0x00, 0x01, 0xe0, 0x00,
  0x3f, 0xff, 0xf8, 0xf1, 0xe0, 0x3f, 0x01, 0xe0, 0x00, 0x00, 0xf0, 0x00, 0x00, 0x01, 0xe0, 0x00,
  0x38, 0x00, 0x38, 0xf1, 0xe0, 0x3f, 0x01, 0xe0, 0x00, 0x00, 0xf0, 0x00, 0x00, 0x01, 0xe0, 0x00,
  0x38, 0x00, 0x38, 0xf1, 0xe0, 0x7f, 0x01, 0xe7, 0xff, 0xf0, 0xff, 0xc3, 0xff, 0xf9, 0xff, 0xfc,
  0x38, 0x00, 0x38, 0xf0, 0xf0, 0x7f, 0x83, 0xc7, 0xff, 0xf8, 0xff, 0xc7, 0xff, 0xf9, 0xff, 0xfe,
  0x38, 0x00, 0x38, 0xf0, 0xf0, 0x7f, 0x83, 0xc7, 0xff, 0xfc, 0xff, 0xc7, 0xff, 0xf9, 0xff, 0xfe,
  0x38, 0x00, 0x38, 0xf0, 0x70, 0xf3, 0xc3, 0x80, 0x00, 0x3c, 0xf0, 0x07, 0x00, 0x01, 0xe0, 0x0e,
  0x38, 0x00, 0x38, 0xf0, 0x78, 0xf3, 0xc7, 0x80, 0x00, 0x3c, 0xf0, 0x07, 0x00, 0x01, 0xe0, 0x0e,
  0x3f, 0xff, 0xf8, 0xf0, 0x78, 0xf3, 0xc7, 0x80, 0x00, 0x3c, 0xf0, 0x07, 0x00, 0x01, 0xe0, 0x0e,
  0x3f, 0xff, 0xf8, 0xf0, 0x3d, 0xe1, 0xef, 0x07, 0xff, 0xfc, 0xf0, 0x07, 0x00, 0x01, 0xe0, 0x0e,
  0x3f, 0xff, 0xf8, 0xf0, 0x3d, 0xe1, 0xef, 0x07, 0xff, 0xfc, 0xf0, 0x07, 0x00, 0x01, 0xe0, 0x0e,
  0x3f, 0xff, 0xe0, 0xf0, 0x3d, 0xc0, 0xef, 0x07, 0xff, 0xfc, 0xf0, 0x07, 0x00, 0x01, 0xe0, 0x0e,
  0x38, 0x0f, 0x80, 0xf0, 0x1f, 0xc0, 0xfe, 0x07, 0x80, 0x3c, 0xf0, 0x07, 0x00, 0x01, 0xe0, 0x0e,
  0x38, 0x07, 0xc0, 0xf0, 0x1f, 0xc0, 0xfe, 0x07, 0x80, 0x3c, 0xf0, 0x07, 0x00, 0x01, 0xe0, 0x0e,
  0x38, 0x03, 0xe0, 0xf0, 0x1f, 0x80, 0x7e, 0x07, 0x80, 0x3c, 0xf0, 0x07, 0x00, 0x01, 0xe0, 0x0e,
  0x38, 0x01, 0xf0, 0xf0, 0x0f, 0x80, 0x7c, 0x07, 0xff, 0xfc, 0x7f, 0xc7, 0xff, 0xf9, 0xe0, 0x0e,
  0x38, 0x00, 0xf0, 0xf0, 0x0f, 0x80, 0x7c, 0x03, 0xff, 0xfc, 0x7f, 0xc7, 0xff, 0xf9, 0xe0, 0x0e,
  0x38, 0x00, 0xf8, 0xf0, 0x07, 0x00, 0x38, 0x03, 0xff, 0xfc, 0x3f, 0xc3, 0xff, 0xf9, 0xe0, 0x0e,
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
};

const unsigned char batt_icon_empty16x8[] PROGMEM = {
  0xff, 0xfe, 0x80, 0x02, 0xa0, 0x03, 0xa0, 0x03, 0xa0, 0x03, 0xa0, 0x03, 0x80, 0x02, 0xff, 0xfe
};

const unsigned char batt_icon_low16x8[] PROGMEM = {
  0xff, 0xfe, 0x80, 0x02, 0xbc, 0x03, 0xbc, 0x03, 0xbc, 0x03, 0xbc, 0x03, 0x80, 0x02, 0xff, 0xfe
};

const unsigned char batt_icon_high16x8[] PROGMEM = {
  0xff, 0xfe, 0x80, 0x02, 0xbf, 0xc3, 0xbf, 0xc3, 0xbf, 0xc3, 0xbf, 0xc3, 0x80, 0x02, 0xff, 0xfe
};

const unsigned char batt_icon_full16x8[] PROGMEM = {
  0xff, 0xfe, 0x80, 0x02, 0xbf, 0xfb, 0xbf, 0xfb, 0xbf, 0xfb, 0xbf, 0xfb, 0x80, 0x02, 0xff, 0xfe
};

const unsigned char chg_icon8x8[] PROGMEM = {
  0x00, 0x08, 0x10, 0x30, 0x7e, 0x0c, 0x08, 0x10
};

const unsigned char BLE8x8[] PROGMEM = {
  0x10, 0x18, 0x54, 0x38, 0x54, 0x18, 0x10, 0x00,
};

const unsigned char notif16x16[] PROGMEM = {
  0x01, 0x80, 0x03, 0xc0, 0x0c, 0x30, 0x10, 0x08, 0x00, 0x00, 0x20, 0x04, 0x20, 0x04, 0x20, 0x04,
  0x20, 0x04, 0x20, 0x04, 0x40, 0x02, 0x80, 0x01, 0x80, 0x01, 0xff, 0xff, 0x02, 0x40, 0x01, 0x80,
};
const unsigned char flappybird_frame_1[] = { 0x03, 0xF0, 0x0C, 0x48, 0x10, 0x84, 0x78, 0x8A, 0x84, 0x8A, 0x82, 0x42, 0x82, 0x3E, 0x44, 0x41, 0x38, 0xBE, 0x20, 0x41, 0x18, 0x3E, 0x07, 0xC0 };
const unsigned char flappybird_frame_2[] = { 0x03, 0xF0, 0x0C, 0x48, 0x10, 0x84, 0x20, 0x8A, 0x40, 0x8A, 0x40, 0x42, 0x7C, 0x3E, 0x82, 0x41, 0x84, 0xBE, 0x88, 0x41, 0x78, 0x3E, 0x07, 0xC0 };
const unsigned char bar_bottom[] = { 0xFF, 0xFF, 0xFF, 0x42, 0x7E, 0x7E, 0x7E, 0x7E, 0x7E, 0x7E, 0x7E, 0x7E, 0x7E, 0x7E, 0x7E, 0x7E, 0x7E, 0x7E, 0x7E, 0x7E };
const unsigned char bar_top[] = { 0x7E, 0x7E, 0x7E, 0x7E, 0x7E, 0x7E, 0x7E, 0x7E, 0x7E, 0x7E, 0x7E, 0x7E, 0x7E, 0x7E, 0x7E, 0x7E, 0x42, 0xFF, 0xFF, 0xFF };

void interr1()
{}

void interr2()
{}

void menu()
{
  first_millis = millis();
  //Button1 = select
  //Button2 = right
  //Button3 = left

  switch (modeInMenu)
  {
    case 0://main screen
      display.clearDisplay();
      display.drawRect(0, 0, 128, 64, 1);
      display.setTextSize(1);
      display.setTextColor(BLACK, WHITE);
      display.setCursor(2, 2);
      display.println("  Main screen");
      display.setTextColor(WHITE);
      display.println(" Stopwatch");
      display.println(" Altimeter");
      display.println(" Compass");
      display.println(" Accelerometer");
      display.println(" Power");
      display.println(" FB");
      display.display();
      if (Button1.wasPressed())
      {
        button_buzz();
        mode = 0;
      }
      break;
    case 1://Stopwatch
      display.clearDisplay();
      display.drawRect(0, 0, 128, 64, 1);
      display.setTextSize(1);
      display.setTextColor(WHITE);
      display.setCursor(2, 2);
      display.println(" Main screen");
      display.setTextColor(BLACK, WHITE);
      display.println("  Stopwatch");
      display.setTextColor(WHITE);
      display.println(" Altimeter");
      display.println(" Compass");
      display.println(" Accelerometer");
      display.println(" Power");
      display.println(" FB");
      display.display();
      if (Button1.wasPressed())
      {
        button_buzz();
        mode = 1;
      }
      break;
    case 2://Alti
      display.clearDisplay();
      display.drawRect(0, 0, 128, 64, 1);
      display.setTextSize(1);
      display.setTextColor(WHITE);
      display.setCursor(2, 2);
      display.println(" Main screen");
      display.println(" Stopwatch");
      display.setTextColor(BLACK, WHITE);
      display.println("  Altimeter");
      display.setTextColor(WHITE);
      display.println(" Compass");
      display.println(" Accelerometer");
      display.println(" Power");
      display.println(" FB");
      display.display();
      if (Button1.wasPressed())
      {
        button_buzz();
        mode = 2;
      }
      break;
    case 3: //Compass
      display.clearDisplay();
      display.drawRect(0, 0, 128, 64, 1);
      display.setTextSize(1);
      display.setTextColor(WHITE);
      display.setCursor(2, 2);
      display.println(" Main screen");
      display.println(" Stopwatch");
      display.println(" Altimeter");
      display.setTextColor(BLACK, WHITE);
      display.println("  Compass");
      display.setTextColor(WHITE);
      display.println(" Accelerometer");
      display.println(" Power");
      display.println(" FB");
      display.display();
      if (Button1.wasPressed())
      {
        button_buzz();
        mode = 3;
      }
      break;
    case 4: //Accelprint
      display.clearDisplay();
      display.drawRect(0, 0, 128, 64, 1);
      display.setTextSize(1);
      display.setTextColor(WHITE);
      display.setCursor(2, 2);
      display.println(" Main screen");
      display.println(" Stopwatch");
      display.println(" Altimeter");
      display.println(" Compass");
      display.setTextColor(BLACK, WHITE);
      display.println("  Accelerometer");
      display.setTextColor(WHITE);
      display.println(" Power");
      display.println(" FB");
      display.display();
      if (Button1.wasPressed())
      {
        button_buzz();
        mode = 4;
      }
      break;
    case 5: //Power
      display.clearDisplay();
      display.drawRect(0, 0, 128, 64, 1);
      display.setTextSize(1);
      display.setTextColor(WHITE);
      display.setCursor(2, 2);
      display.println(" Main screen");
      display.println(" Stopwatch");
      display.println(" Altimeter");
      display.println(" Compass");
      display.println(" Accelerometer");
      display.setTextColor(BLACK, WHITE);
      display.println("  Power");
      display.setTextColor(WHITE);
      display.println(" FB");
      display.display();
      if (Button1.wasPressed())
      {
        mode = 5;
      }
      break;
    case 6: //Power
      display.clearDisplay();
      display.drawRect(0, 0, 128, 64, 1);
      display.setTextSize(1);
      display.setTextColor(WHITE);
      display.setCursor(2, 2);
      display.println(" Main screen");
      display.println(" Stopwatch");
      display.println(" Altimeter");
      display.println(" Compass");
      display.println(" Accelerometer");
      display.println("  Power");
      display.setTextColor(BLACK, WHITE);
      display.println(" FB");
      display.display();
      if (Button1.wasPressed())
      {
        mode = 6;
      }
      break;
  }

  if (Button2.wasPressed())
  {
    button_buzz();
    modeInMenu++;
  }

  if (Button3.wasPressed())
  {
    button_buzz();
    modeInMenu = modeInMenu - 1;
  }

  if (modeInMenu > 6)
  {
    modeInMenu = 6;
  }

  if (modeInMenu < 0)
  {
    modeInMenu = 0;
  }
}

void show_mode()
{
  switch (mode)
  {
    case 0:
      main_screen();
      break;
    case 1:
      chrono();
      break;
    case 2:
      altimeter();
      break;
    case 3:
      compass();
      break;
    case 4:
      accel();
      break;
    case 5:
      powerStats();
      break;
    case 6:
      flappy();
      break;
    case 7:
      notifOther();
      break;
    case 8:
      notifIncomingCall();
      break;
    case 9:
      notifMissedCall();
      break;
    case 10:
      notifVoiceMail();
      break;
    case 11:
      notifSocial();
      break;
    case 12:
      notifSchedule();
      break;
    case 13:
      notifEmail();
      break;
    case 14:
      notifNews();
      break;
    case 15:
      notifHealth();
      break;
    case 16:
      notifBuisness();
      break;
    case 17:
      notifLocation();
      break;
    case 18:
      notifEntertainment();
      break;
  }
}

void main_screen()
{
  display.clearDisplay();

  display.drawRect(0, 0, 128, 64, 1);

  display.drawFastHLine(0, 14, 128, 1);
  display.drawFastHLine(0, 48, 128, 1);

  //BATT STAT
  //  if (lipo.soc() == 100)
  //  {
  //    display.drawBitmap(5, 52, batt_icon_full16x8, 16, 8, 1);
  //  }
  //  if (lipo.soc() < 100 && lipo.soc() > 50)
  //  {
  //    display.drawBitmap(5, 52, batt_icon_high16x8, 16, 8, 1);
  //  }
  //  if (lipo.soc() < 50 && lipo.soc() > 30)
  //  {
  //    display.drawBitmap(5, 52, batt_icon_low16x8, 16, 8, 1);
  //  }
  //  if (lipo.soc() < 30)
  //  {
  //    display.drawBitmap(5, 52, batt_icon_empty16x8, 16, 8, 1);
  //  }
  //
  //  display.setTextSize(1);
  //  display.setTextColor(WHITE);
  //  display.setCursor(25, 52);
  //  display.print(lipo.soc());
  //  display.print("%");
  //
  //  int pw = lipo.power();
  //
  //  if (pw > 0)
  //  {
  //    display.drawBitmap(50, 52, chg_icon8x8, 8, 8, 1);
  //  }

  display.setTextSize(1);
  display.setTextColor(WHITE);
  display.setCursor(24, 4);

  int wd ; // WeekDay ( Sunday - 0,Monday- 1,.....)

  int d = rtc.getDay();

  int m = rtc.getMonth();

  int y = 2000 + rtc.getYear();

  wd = ((d += m < 3 ? y-- : y - 2, 23 * m / 9 + d + 4 + y / 4 - y / 100 + y / 400) % 7);


  //Serial.print(wd);
  display.print(daysOfTheWeek[wd]);
  display.print(" ");

  if (rtc.getDay() < 10)
  {
    display.print("0");
    display.print(rtc.getDay());
  }
  if (rtc.getDay() >= 10)
  {
    display.print(rtc.getDay());
  }
  display.print('/');
  if (rtc.getMonth() < 10)
  {
    display.print("0");
    display.print(rtc.getMonth());
  }
  if (rtc.getMonth() >= 10)
  {
    display.print(rtc.getMonth());
  }
  display.print('/');
  display.print(rtc.getYear());

  display.setTextSize(2);
  display.setTextColor(WHITE);
  display.setCursor(15, 25);

  if (rtc.getHours() < 10)
  {
    display.print('0');
    display.print(rtc.getHours());
  }
  else
  {
    display.print(rtc.getHours());
  }
  display.print(':');
  if (rtc.getMinutes() < 10)
  {
    display.print('0');
    display.print(rtc.getMinutes());
  }
  else
  {
    display.print(rtc.getMinutes());
  }
  display.print(':');
  if (rtc.getSeconds() < 10)
  {
    display.print('0');
    display.print(rtc.getSeconds());
  }
  else
  {
    display.print(rtc.getSeconds());
  }

  display.setTextSize(1);
  display.setTextColor(WHITE);
  display.setCursor(100, 52);
  int temp = bmp.readTemperature();
  display.print(temp);
  display.print((char)247);
  display.print("C");

  if (bleConnected == true)
  {
    display.drawBitmap(90, 52, BLE8x8, 8, 8, 1);
  }

  display.display();
  timer = millis();
}
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
void loop()
{
  if (rtc.getSeconds() % 2 == 0)
  {
    blePeripheral.poll();
  }
  shouldBeSleeping = false;
  Button1.read();
  Button2.read();
  Button3.read();

  if (Button1.pressedFor(1500) or timer - first_millis >= timeout)
  {
    shouldBeSleeping = true;
  }

  switch (shouldBeSleeping)
  {
    case 0:
      break;
    case 1:
      display.clearDisplay();
      display.display();
      attachInterrupt(B1Pin, interr1, LOW);
      //attachInterrupt(BNO_INT_PIN, interr2, HIGH);
      //bno.enableAnyMotion(150, 12);
      LowPower.standby();
      display.drawBitmap(0, 0, RWatch_logo, 128, 64, 1);
      display.display();
      //bno.resetInterrupt();
      //bno.disableAnyMotion();
      detachInterrupt(B1Pin);
      detachInterrupt(BNO_INT_PIN);
      first_millis = millis();
      inMenu = 0;
      mode = 0;
      modeInMenu = 0;
      shouldBeSleeping = false;
  }

  switch (inMenu)
  {
    case 0:
      show_mode();
      break;
    case 1:
      menu();
      break;
  }

  if (Button1.wasPressed())
  {
    inMenu++;
    button_buzz();
    if (inMenu > 1)
    {
      inMenu = 0;
    }
  }
}

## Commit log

2016-07-28 Imported Files
    [Adafruit Feather M0 Basic rev C.brd, Adafruit Feather M0 Basic rev C.sch, Adafruit_1.3_128x64_OLED.brd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]
2016-07-28 Update Sensor Datasheet
2016-10-03 Added Logo
    [RWatch.dxf]
2016-11-04 Updated brd
    [Adafruit Feather M0 Basic rev C.brd]
2016-11-04 Revert "Initial firmware"
    This reverts commit 7344d446994e38cccda72d7284f94b4ed1833ed1.
    [RWatch.ino]
2016-11-04 Revert "Revert "Initial firmware""
    This reverts commit e97536be538c077792ab8bd13cb232262cd61612.
    [RWatch.ino]
2016-11-04 Changed IMU to BNO055 and RTC to internal RTC
2016-11-04 Added temperature/pressure, battery monitoring, and haptic vibration
    [RWatch.ino]
2016-11-27 Switched BNO-055 library to Arduino.org NAxisMotion library for interrupt support
2016-12-14 Added flappy bird game
    Code by https://hackaday.io/project/3981-flappy-bird-on-arduino
2019-12-18 Added PCB files
    [RWatch.brd, RWatch.sch]
2019-12-18 Added revA schematic pdf

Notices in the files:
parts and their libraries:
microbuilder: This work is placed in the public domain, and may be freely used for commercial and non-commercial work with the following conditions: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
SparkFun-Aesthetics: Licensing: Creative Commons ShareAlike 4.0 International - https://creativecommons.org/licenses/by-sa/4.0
